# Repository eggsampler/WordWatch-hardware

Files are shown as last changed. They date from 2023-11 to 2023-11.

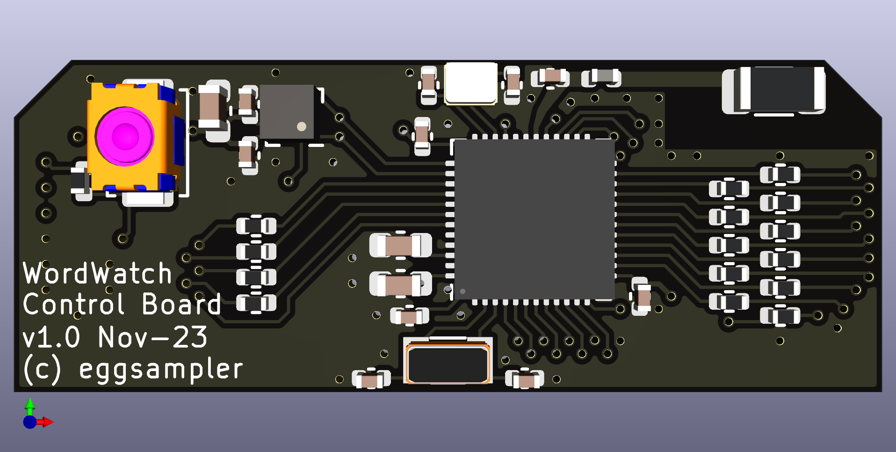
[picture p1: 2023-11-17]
ControllerBoard/plots/3d-front.png

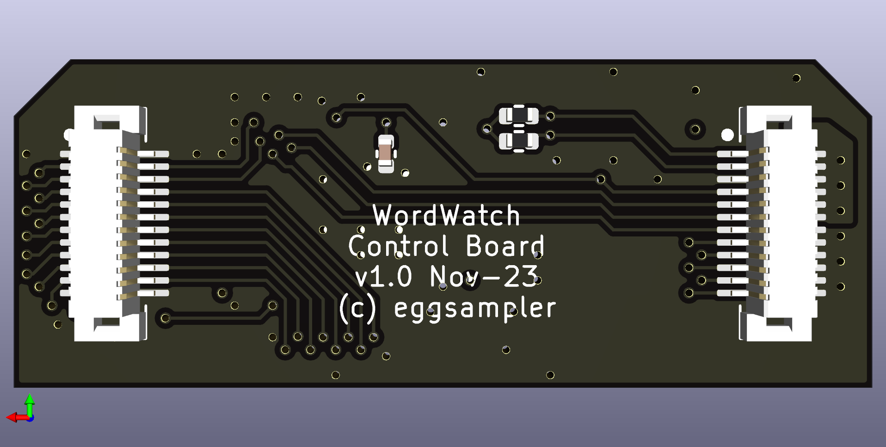
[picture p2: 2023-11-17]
ControllerBoard/plots/3d-back.png

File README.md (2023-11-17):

# WordWatch-hardware

|  | Schematic | 2D PCB | 3D |
| --- | --- | --- | --- |
| Controller Board | [ControllerBoard.pdf](ControllerBoard/plots/ControllerBoard.pdf) | [ControllerBoard__Assembly.pdf](ControllerBoard/plots/ControllerBoard__Assembly.pdf) | [ControllerBoard.wrl](ControllerBoard/plots/ControllerBoard.wrl) |
| LED Board | [LEDBoard.pdf](LEDBoard/plots/LEDBoard.pdf) | [LEDBoard__Assembly.pdf](LEDBoard/plots/LEDBoard__Assembly.pdf) | [LEDBoard.wrl](LEDBoard/plots/LEDBoard.wrl) |
| Programming Board | [ProgrammingBoard.pdf](ProgrammingBoard/plots/ProgrammingBoard.pdf) | [ProgrammingBoard__Assembly.pdf](ProgrammingBoard/plots/ProgrammingBoard__Assembly.pdf) | [ProgrammingBoard.wrl](ProgrammingBoard/plots/ProgrammingBoard.wrl) |

PNG outputs for 2D and 3D PCB views also in each plot folder.

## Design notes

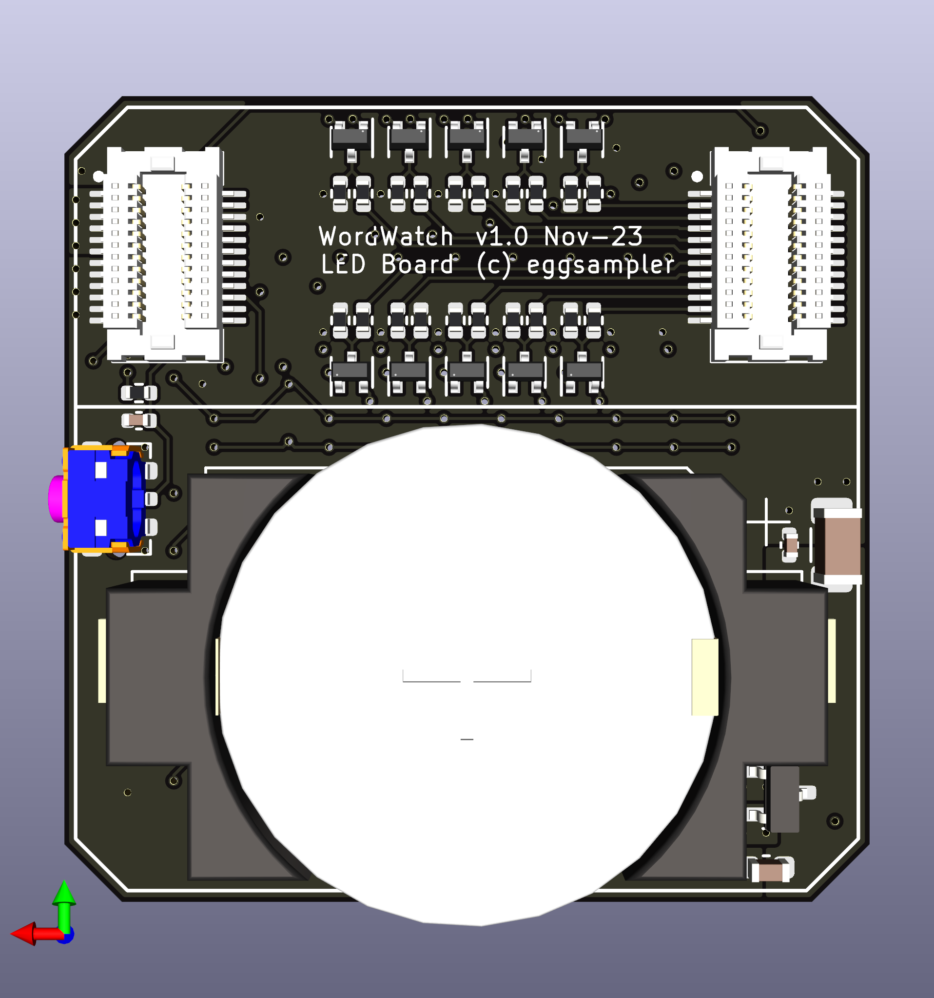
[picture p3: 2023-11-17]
LEDBoard/plots/3d-back.png

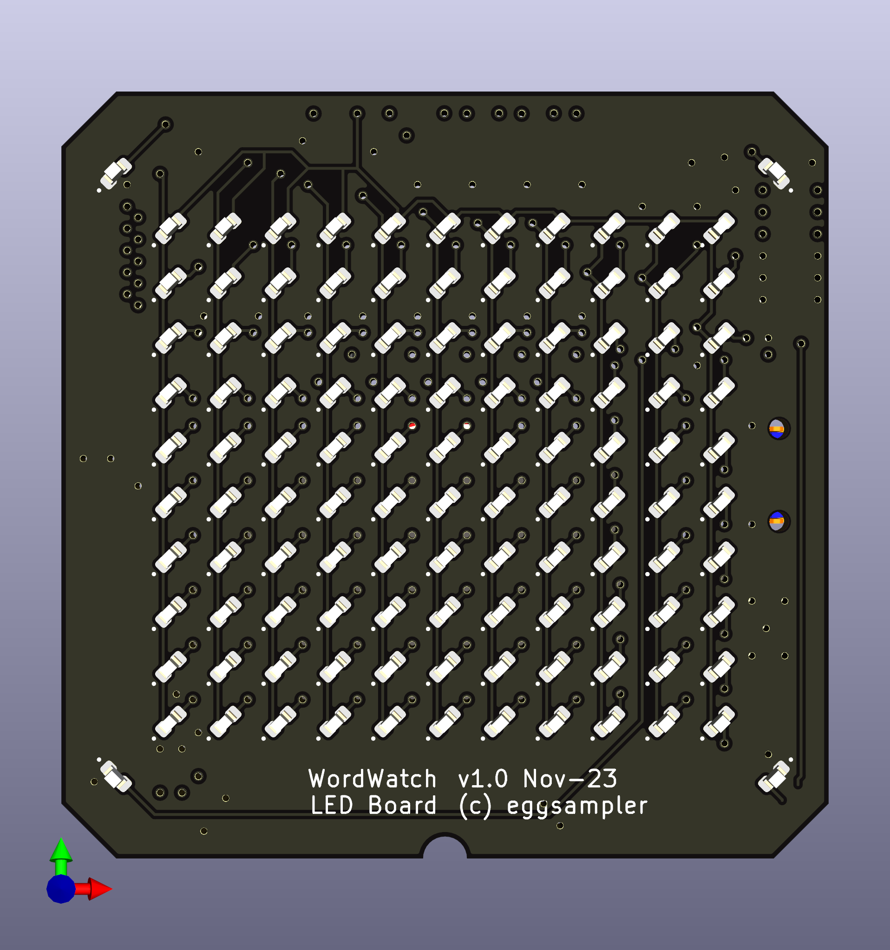
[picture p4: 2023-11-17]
LEDBoard/plots/3d-front.png

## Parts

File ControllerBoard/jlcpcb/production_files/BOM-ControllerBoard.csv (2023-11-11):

Comment | Designator | Footprint | LCSC
1k | R10,R11,R12,R13,R14,R15,R16,R17,R18,R4,R5,R6,R7,R8,R9 | R_0402_1005Metric | C11702
3.9nH | L1 | L_0402_1005Metric | C14033
nRF52810-QFxx | U3 | QFN-48-1EP_6x6mm_P0.4mm_EP4.6x4.6mm | C141828
100n | C1,C10,C13,C4,C9 | C_0402_1005Metric | C1525
100p | C11 | C_0402_1005Metric | C1546
12p | C12,C15,C16,C7 | C_0402_1005Metric | C1547
LIS2DE12 | U2 | LGA-12_2x2mm_P0.5mm | C155639
1u | C6 | C_0603_1608Metric | C15849
4.7u | C5,C8 | C_0603_1608Metric | C19666
4.7k | R1,R2,R3 | R_0402_1005Metric | C25900
RESET | SW1 | SW_Push_SPST_NO_Alps_SKRK | C262416
X0511WVS-24AS-LPV01 | J1,J2 | X0511WVS-24AS-LPV01 | C2925345
32MHz | Y2 | Oscillator_SMD_Abracon_ASCO-4Pin_1.6x1.2mm | C2965582
32.768kHz | Y1 | Crystal_SMD_3215-2Pin_3.2x1.5mm | C32346
0.8p | C14 | C_0402_1005Metric | C327032
KH3216-A55 | AE1 | R_1206_3216Metric | C484541

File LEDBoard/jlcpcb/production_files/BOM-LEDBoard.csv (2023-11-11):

Comment | Designator | Footprint | LCSC
SKRTLA | SW1 | SW_Push_1P1T-MP_NO_Horizontal_Alps_SKRTLAE010 | C110293
1k | R13,R14,R15,R16,R17,R18,R19,R20,R21,R22,R23,R24,R25,R26,R27,R28,R29,R30,R31,R32 | R_0402_1005Metric | C11702
100uF | C1 | C_1206_3216Metric | C15008
AO3401A | Q1 | SOT-23 | C15127
10uF | C3 | C_0603_1608Metric | C19702
DMG1012T | Q10,Q11,Q2,Q3,Q4,Q5,Q6,Q7,Q8,Q9 | SOT-523 | C20512
CR2032 | BT1 | BatteryHolder_Keystone_1060_1x2032 | C238069
10k | R7 | R_0402_1005Metric | C25744
X0511FVS-24AS-LPV01 | J1,J2 | X0511FVS-24AS-LPV01 | C2925346
LED_Small | D1,D10,D100,D101,D102,D103,D104,D105,D106,D107,D108,D109,D11,D110,D111,D112,D113,D114,D12,D13,D14,D15,D16,D17,D18,D19,D2,D20,D21,D22,D23,D24,D25,D26,D27,D28,D29,D3,D30,D31,D32,D33,D34,D35,D36,D37,D38,D39,D4,D40,D41,D42,D43,D44,D45,D46,D47,D48,D49,D5,D50,D51,D52,D53,D54,D55,D56,D57,D58,D59,D6,D60,D61,D62,D63,D64,D65,D66,D67,D68,D69,D7,D70,D71,D72,D73,D74,D75,D76,D77,D78,D79,D8,D80,D81,D82,D83,D84,D85,D86,D87,D88,D89,D9,D90,D91,D92,D93,D94,D95,D96,D97,D98,D99 | LED_0402_1005Metric | C434448
1uF | C2,C4 | C_0402_1005Metric | C52923

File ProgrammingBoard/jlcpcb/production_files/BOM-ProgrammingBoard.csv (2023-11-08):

Comment | Designator | Footprint | LCSC
X0511WVS-24AS-LPV01 | J1,J3 | X0511WVS-24AS-LPV01 | C2925345
X0511FVS-24AS-LPV01 | J2,J4 | X0511FVS-24AS-LPV01 | C2925346
Conn_01x09 | J6 | PinHeader_1x09_P2.54mm_Vertical
Conn_01x06 | J5 | PinHeader_1x06_P2.54mm_Vertical

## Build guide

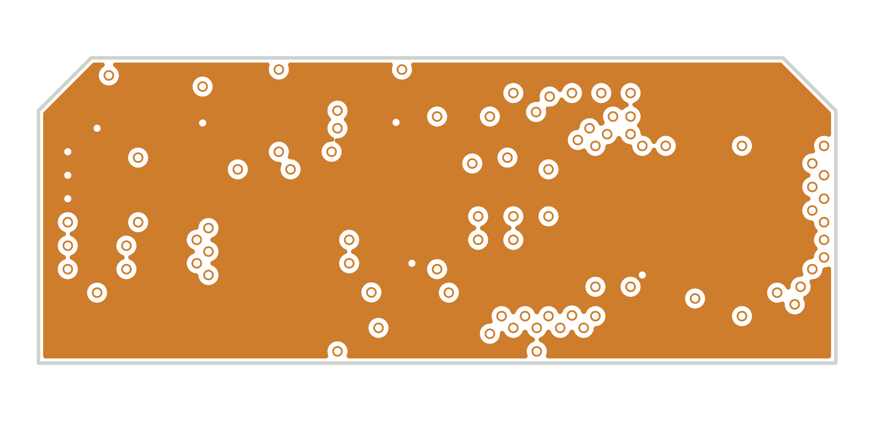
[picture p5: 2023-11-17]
ControllerBoard/plots/ControllerBoard__Assembly-3.png

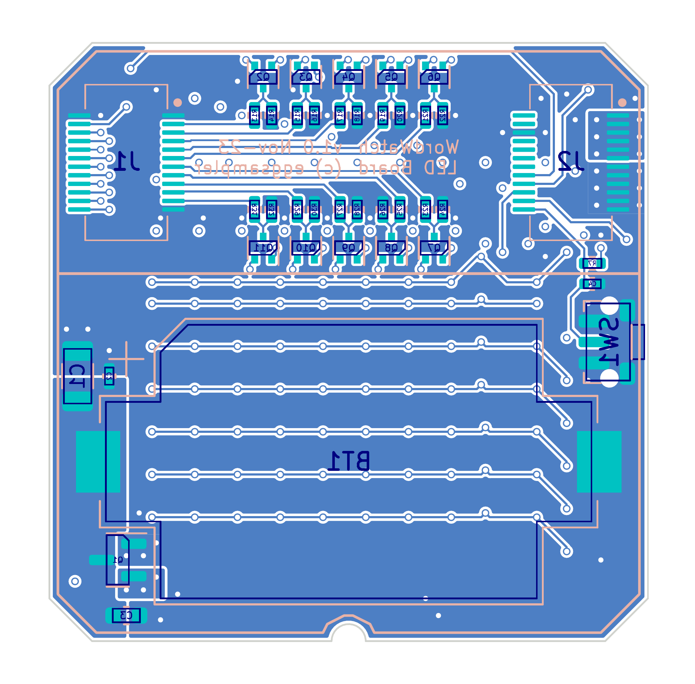
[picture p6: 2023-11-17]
LEDBoard/plots/LEDBoard__Assembly-4.png

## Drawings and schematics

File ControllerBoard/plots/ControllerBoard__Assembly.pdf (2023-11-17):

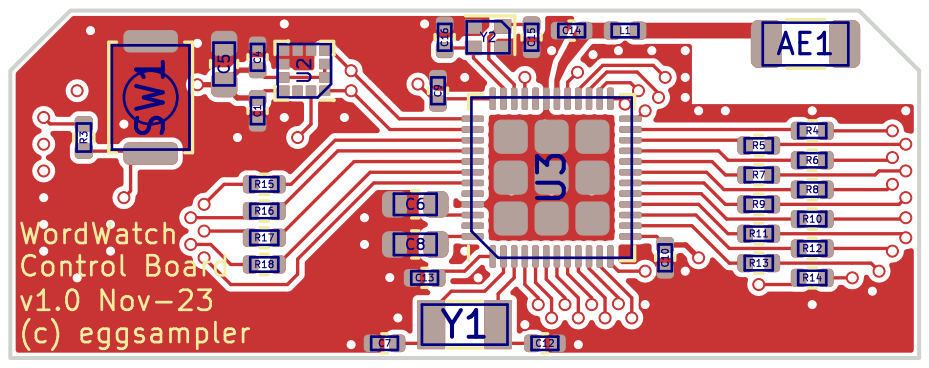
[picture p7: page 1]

Id: 1/1 Title: File: ControllerBoard.kicad_pcb Sheet:

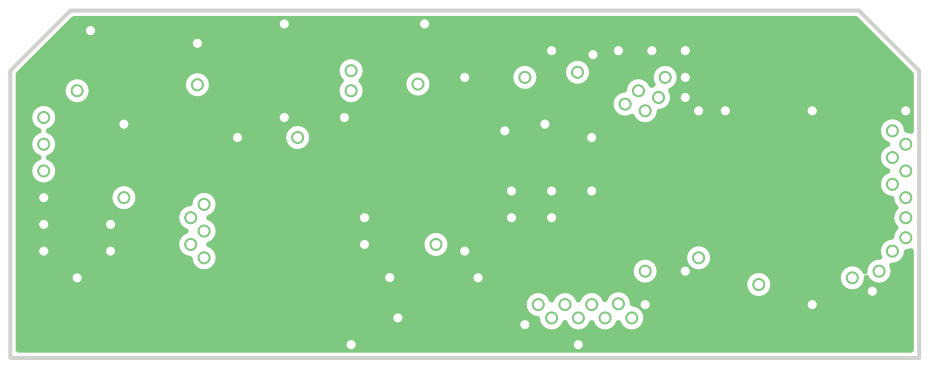
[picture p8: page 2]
D Date: KiCad; kicad; 7.0.8 Size: A4; Rev:

Id: 1/1 Title: File: ControllerBoard.kicad_pcb Sheet:

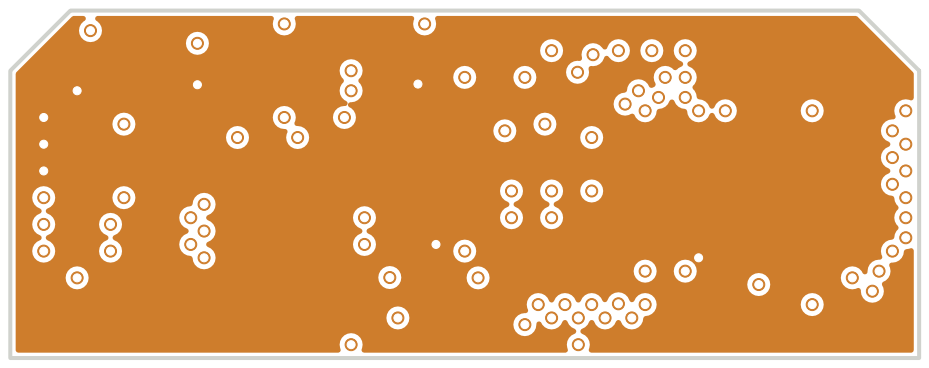
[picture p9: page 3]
D Date: KiCad; kicad; 7.0.8 Size: A4; Rev:

Id: 1/1 Title: File: ControllerBoard.kicad_pcb Sheet:

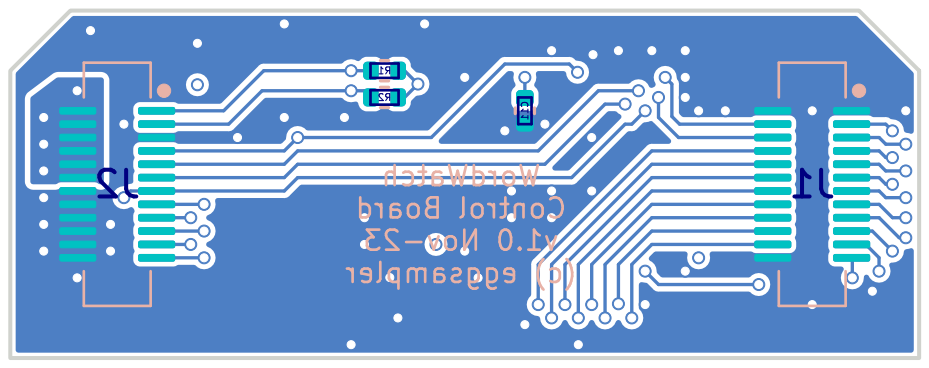
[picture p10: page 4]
C¹¹ R1; R2WordWatch Control Board; v1.0 Nov-23 (c) eggsampler; D Date: KiCad; kicad; 7.0.8 Size: A4; Rev:

Id: 1/1 Title: File: ControllerBoard.kicad_pcb Sheet:

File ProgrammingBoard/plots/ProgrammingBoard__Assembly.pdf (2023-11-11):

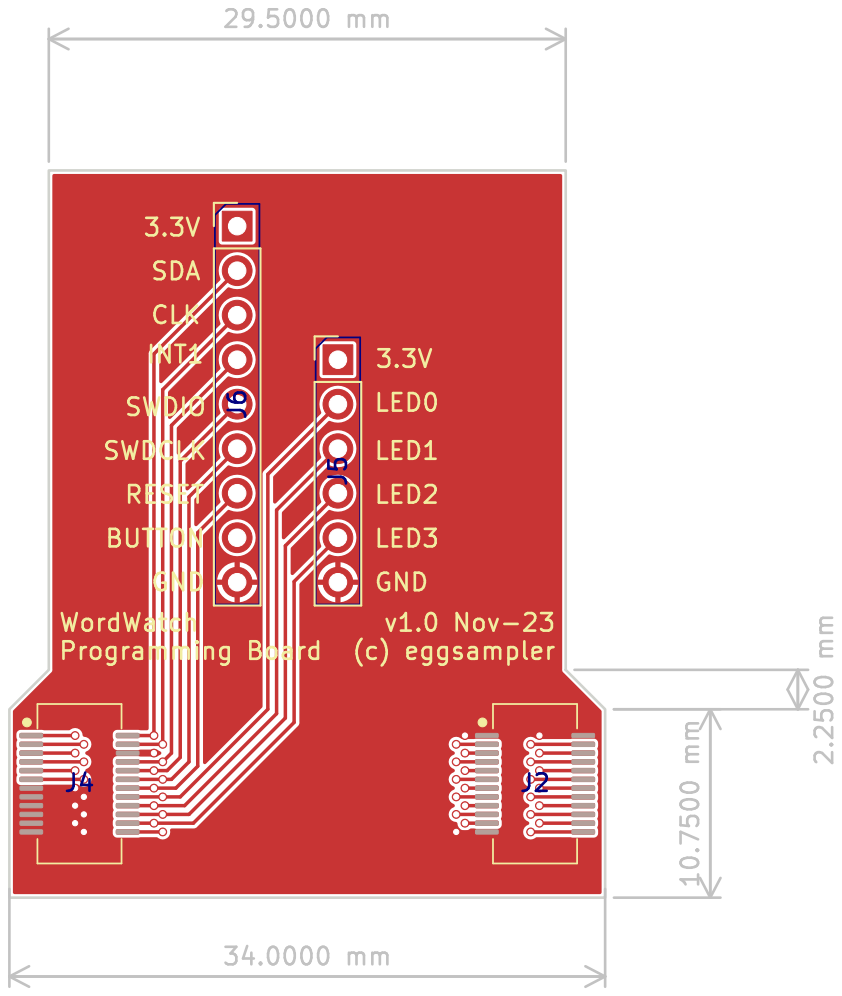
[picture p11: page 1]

Id: 1/1 Title: File: ProgrammingBoard.kicad_pcb Sheet:

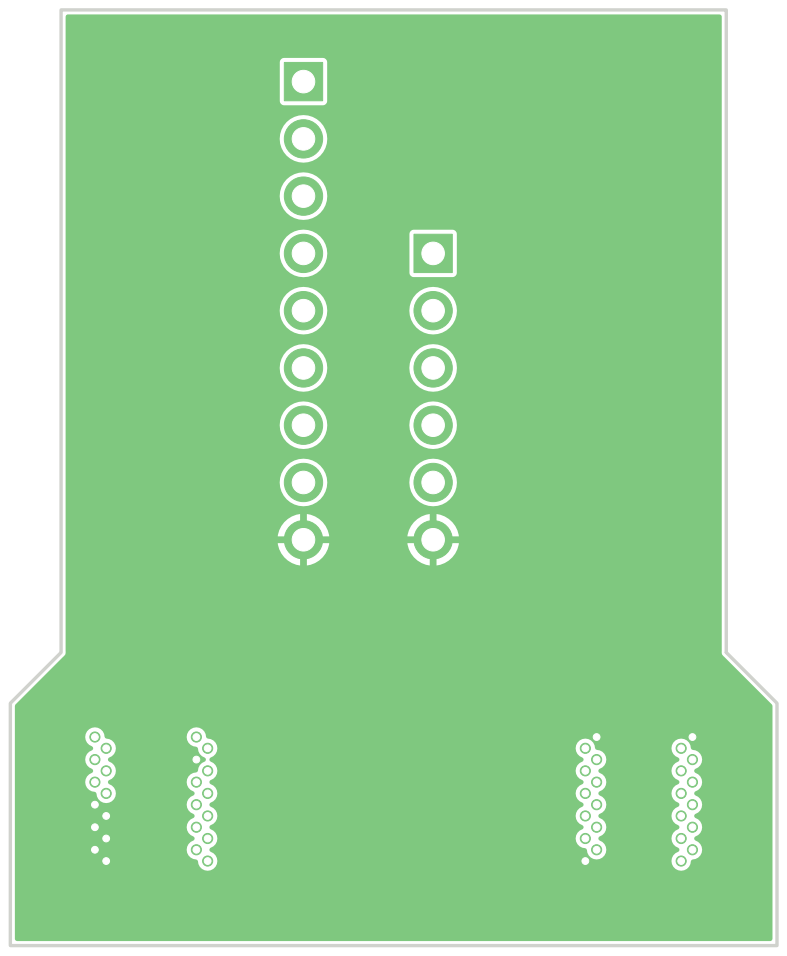
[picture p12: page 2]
D Date: KiCad; kicad; 7.0.8 Size: A4; Rev:

Id: 1/1 Title: File: ProgrammingBoard.kicad_pcb Sheet:

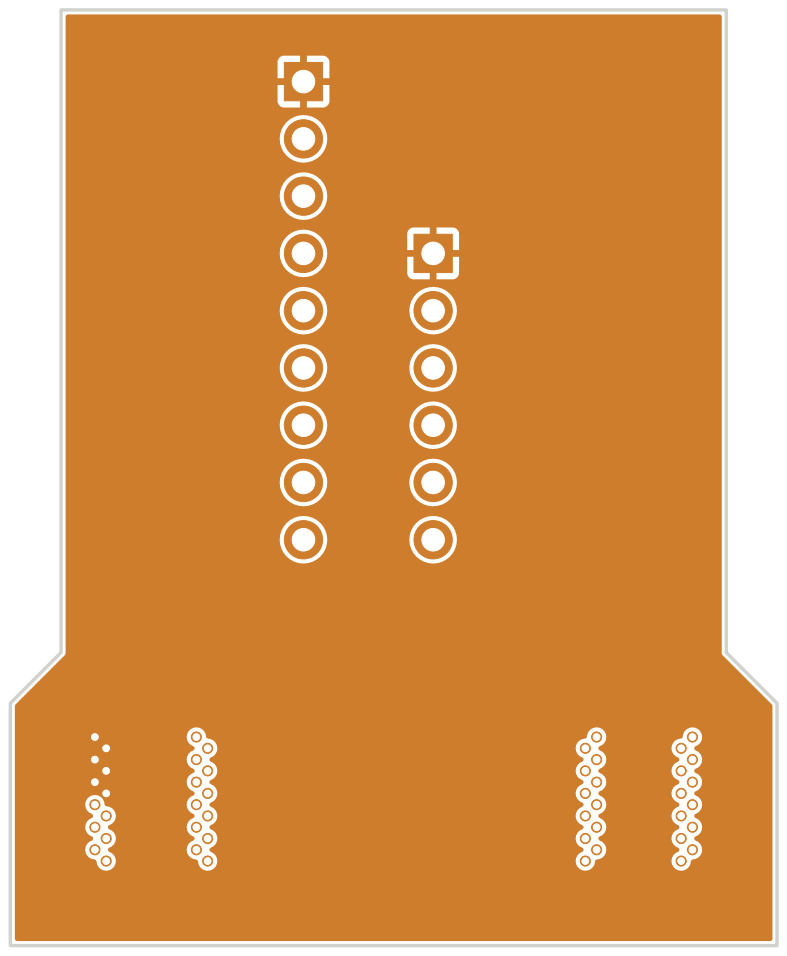
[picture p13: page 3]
D Date: KiCad; kicad; 7.0.8 Size: A4; Rev:

Id: 1/1 Title: File: ProgrammingBoard.kicad_pcb Sheet:

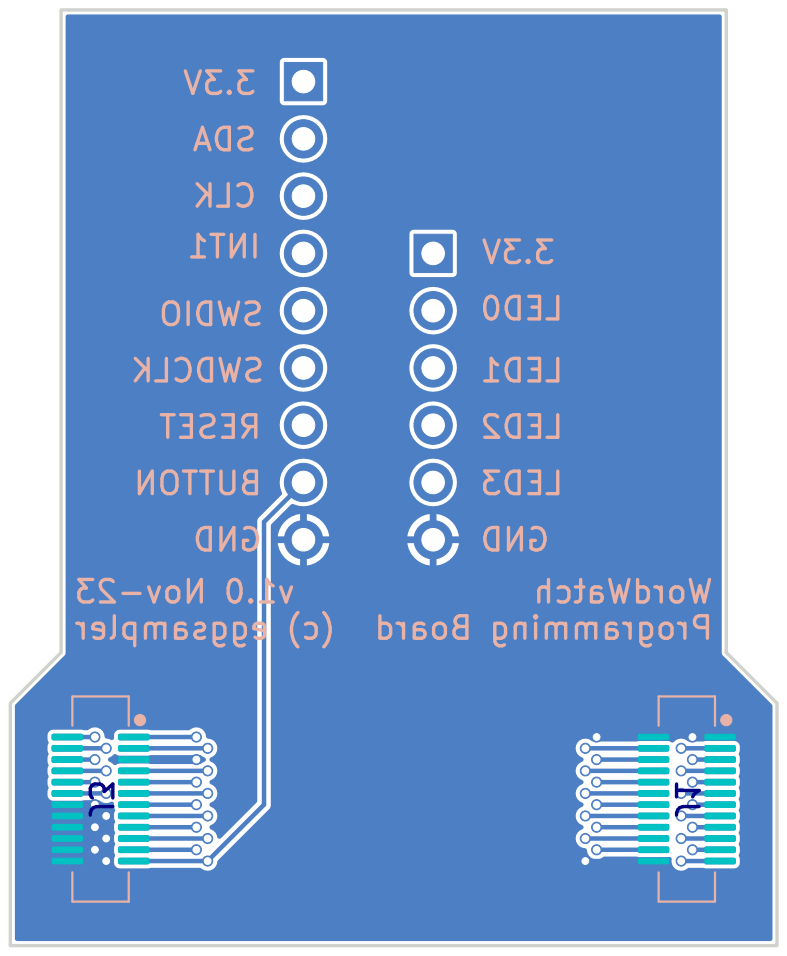
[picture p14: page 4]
J3J1 GND GND; SDA; LED2 SWDIO; LED1; v1.0 Nov-23 (c) eggsampler; INT1; LED3; 3.3V CLK; WordWatch Programming; Board SWDCLK; LED0; 3.3V RESET; BUTTON; D Date: KiCad; kicad; 7.0.8 Size: A4; Rev:

Id: 1/1 Title: File: ProgrammingBoard.kicad_pcb Sheet:

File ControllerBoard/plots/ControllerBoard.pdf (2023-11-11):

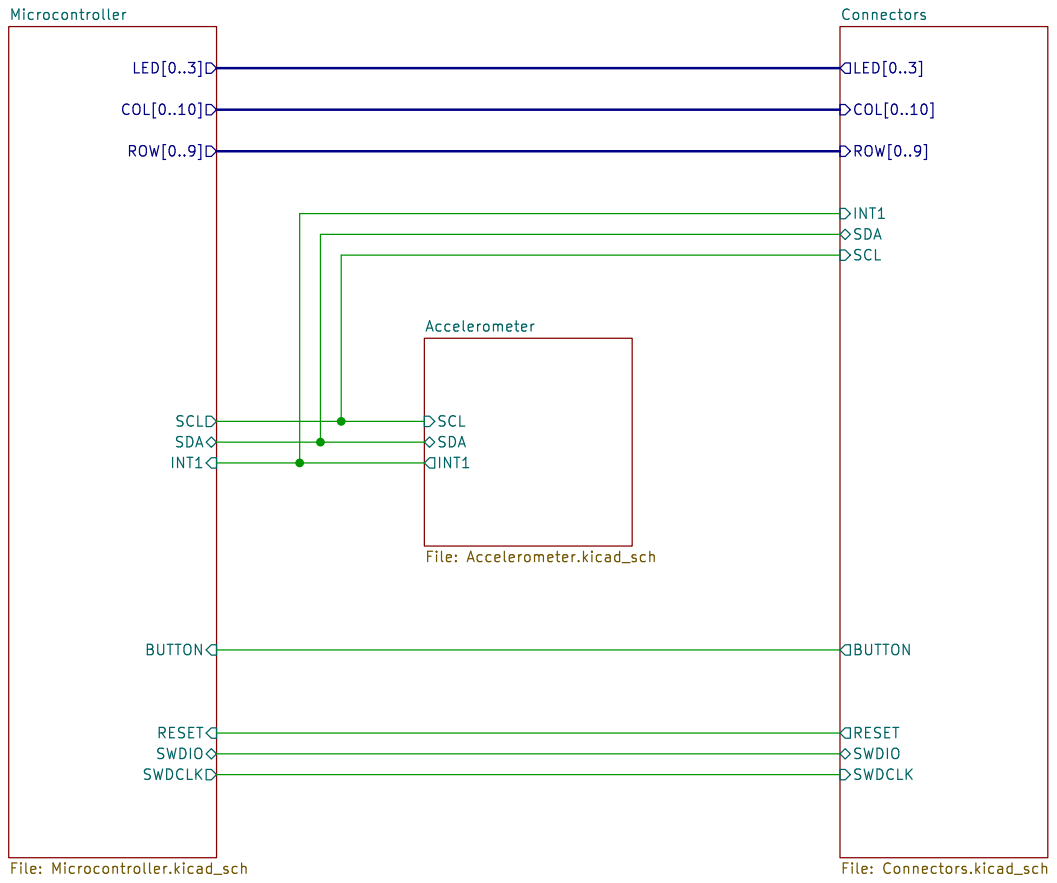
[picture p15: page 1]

SCL Accelerometer File: Accelerometer.kicad_sch

Date: 2023-11-11 File: ControllerBoard.kicad_sch

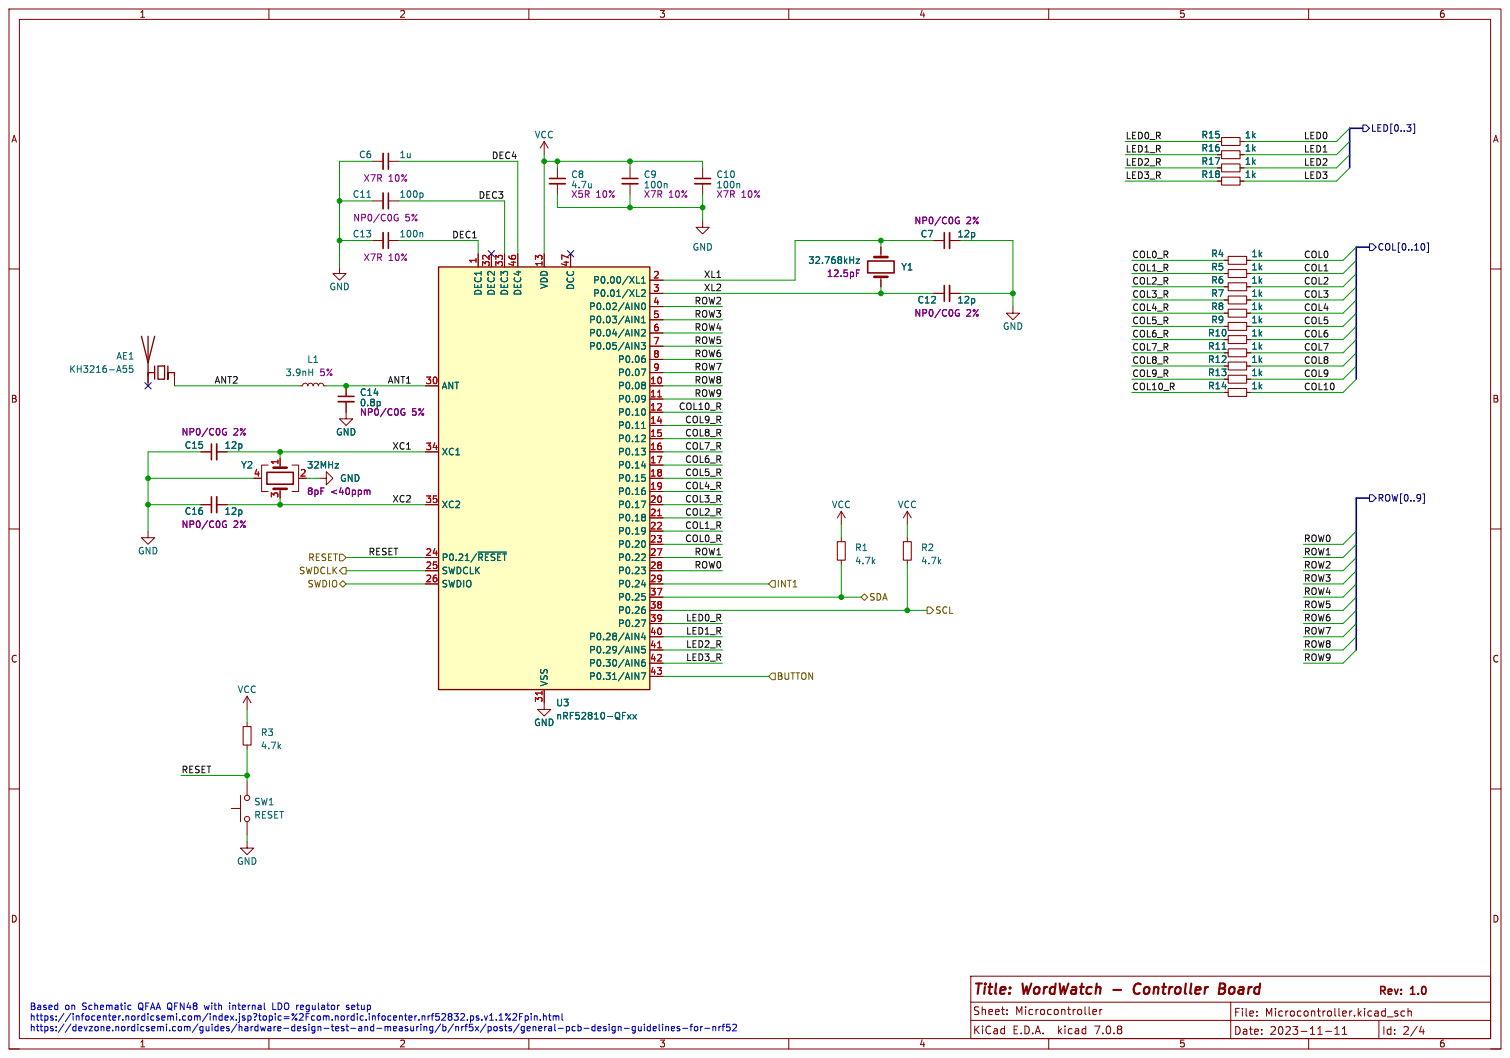
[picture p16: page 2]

1 P0.08 10 P0.09 11 P0.10 12 VDD 13 P0.11 14 P0.12 15 P0.13 16 P0.14 17 P0.15 18 P0.16 19 P0.00/XL1 2 P0.17 20 P0.18 21 P0.19 22 P0.20 23 P0.21/~{RESET} 24 SWDCLK 25 SWDIO 26 P0.22 27 P0.23 28 P0.24 29 P0.01/XL2 3 ANT 30 VSS 31 DEC2 32 DEC3 33 XC1 34 XC2 35 P0.25 37 P0.26 38 P0.27 39 P0.02/AIN0 4 P0.28/AIN4 40 P0.29/AIN5 41 P0.30/AIN6 42 P0.31/AIN7 43 DEC4 46 DCC 47 P0.03/AIN1 5 P0.04/AIN2 6 P0.05/AIN3 7 P0.06 8 P0.07 9 GND
GND

1 P0.08 10 P0.09 11 P0.10 12 VDD 13 P0.11 14 P0.12 15 P0.13 16 P0.14 17 P0.15 18 P0.16 19 P0.00/XL1 2 P0.17 20 P0.18 21 P0.19 22 P0.20 23 P0.21/~{RESET} 24 SWDCLK 25 SWDIO 26 P0.22 27 P0.23 28 P0.24 29 P0.01/XL2 3 ANT 30 VSS 31 DEC2 32 DEC3 33 XC1 34 XC2 35 P0.25 37 P0.26 38 P0.27 39 P0.02/AIN0 4 P0.28/AIN4 40 P0.29/AIN5 41 P0.30/AIN6 42 P0.31/AIN7 43 DEC4 46 DCC 47 P0.03/AIN1 5 P0.04/AIN2 6 P0.05/AIN3 7 P0.06 8 P0.07 9 U3

https://infocenter.nordicsemi.com/index.jsp?topic=%2Fcom.nordic.infocenter.nrf52832.ps.v1.1%2Fpin.html
https://devzone.nordicsemi.com/guides/hardware-design-test-and-measuring/b/nrf5x/posts/general-pcb-design-guidelines-for-nrf52

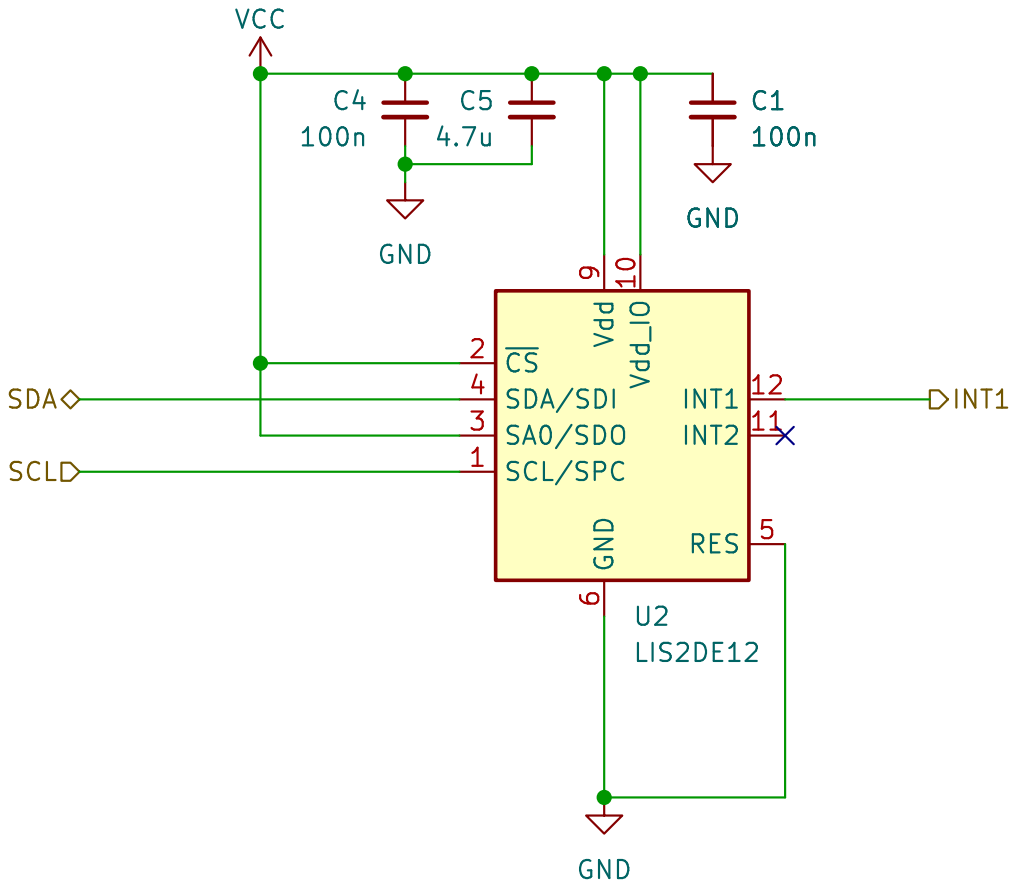
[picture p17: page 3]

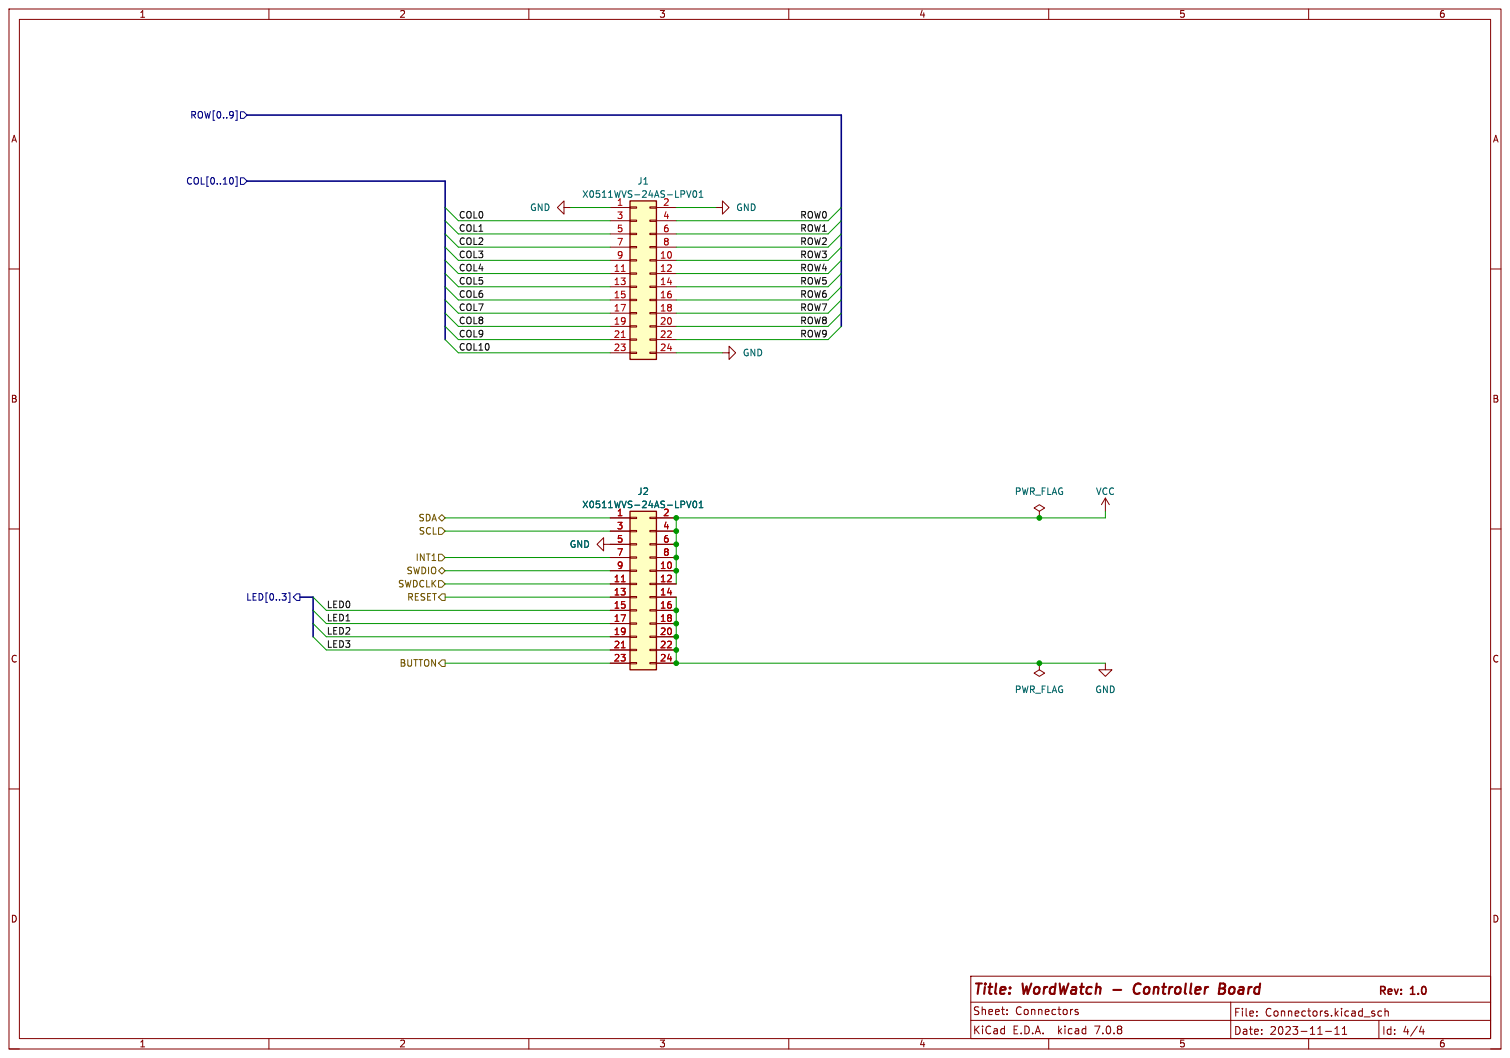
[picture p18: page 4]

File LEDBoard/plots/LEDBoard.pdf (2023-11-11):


17 17 | LED1 18 18
19 19 | 20 20
21 21 | 22 22 LED3
23 23 | 24 24

https://www.ti.com/lit/wp/swra349/swra349.pdf


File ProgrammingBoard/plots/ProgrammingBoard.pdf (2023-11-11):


SCL Connectors File: Connectors.kicad_sch

Programmer File: Programmer.kicad_sch SWDCLK



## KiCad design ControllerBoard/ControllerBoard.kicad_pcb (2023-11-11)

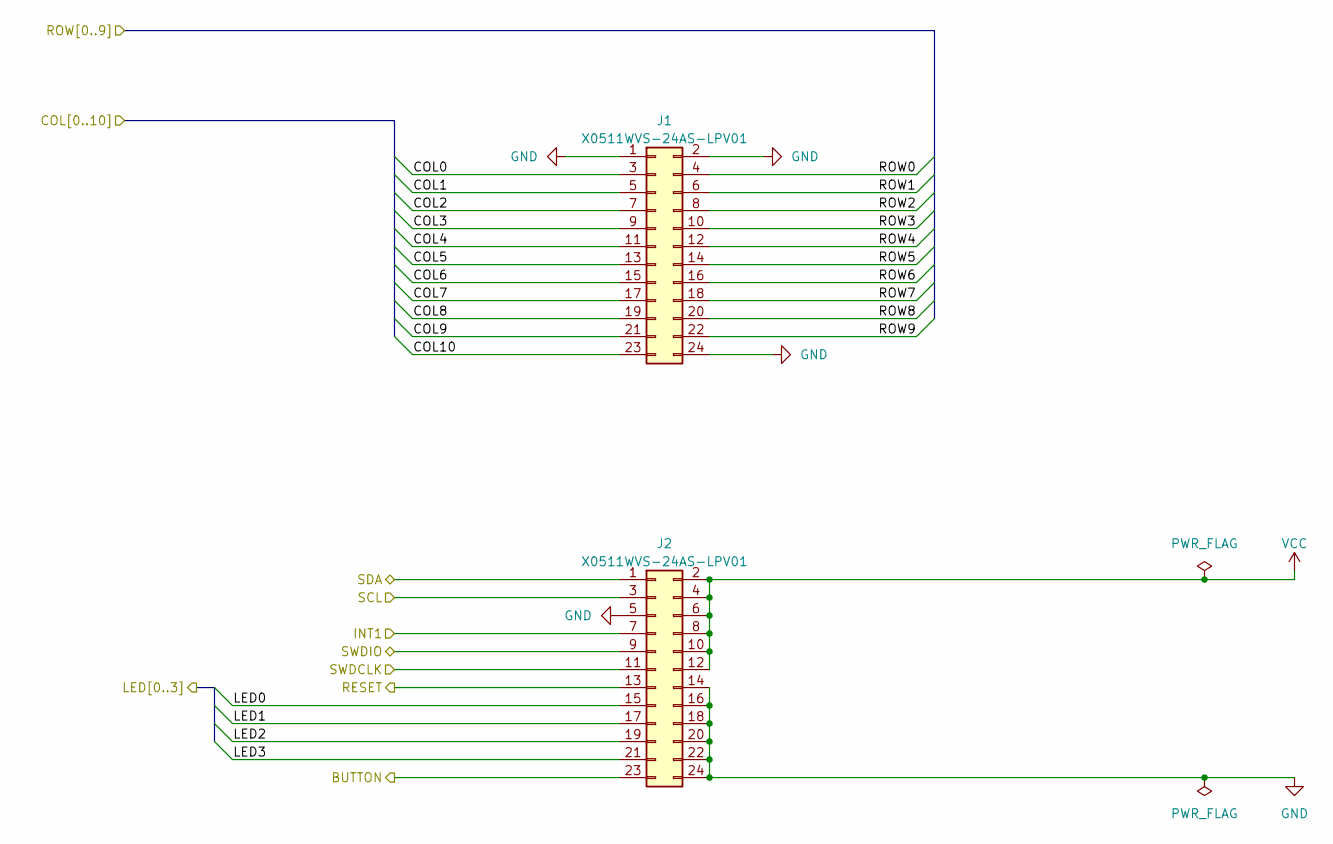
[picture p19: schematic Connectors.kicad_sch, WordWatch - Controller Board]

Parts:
J1, J2: X0511WVS-24AS-LPV01

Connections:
/Accelerometer/INT1: J2.7; also elsewhere on the board
/Accelerometer/SCL: J2.3; also elsewhere on the board
/Accelerometer/SDA: J2.1; also elsewhere on the board
/Connectors/BUTTON: J2.23; also elsewhere on the board
/Connectors/COL0: J1.3; also elsewhere on the board
/Connectors/COL1: J1.5; also elsewhere on the board
/Connectors/COL2: J1.7; also elsewhere on the board
/Connectors/COL3: J1.9; also elsewhere on the board
/Connectors/COL4: J1.11; also elsewhere on the board
/Connectors/COL5: J1.13; also elsewhere on the board
/Connectors/COL6: J1.15; also elsewhere on the board
/Connectors/COL7: J1.17; also elsewhere on the board
/Connectors/COL8: J1.19; also elsewhere on the board
/Connectors/COL9: J1.21; also elsewhere on the board
/Connectors/COL10: J1.23; also elsewhere on the board
/Connectors/LED0: J2.15; also elsewhere on the board
/Connectors/LED1: J2.17; also elsewhere on the board
/Connectors/LED2: J2.19; also elsewhere on the board
/Connectors/LED3: J2.21; also elsewhere on the board
/Connectors/ROW0: J1.4; also elsewhere on the board
/Connectors/ROW1: J1.6; also elsewhere on the board
/Connectors/ROW2: J1.8; also elsewhere on the board
/Connectors/ROW3: J1.10; also elsewhere on the board
/Connectors/ROW4: J1.12; also elsewhere on the board
/Connectors/ROW5: J1.14; also elsewhere on the board
/Connectors/ROW6: J1.16; also elsewhere on the board
/Connectors/ROW7: J1.18; also elsewhere on the board
/Connectors/ROW8: J1.20; also elsewhere on the board
/Connectors/ROW9: J1.22; also elsewhere on the board
/Connectors/SWDCLK: J2.11; also elsewhere on the board
/Connectors/SWDIO: J2.9; also elsewhere on the board
/Microcontroller/RESET: J2.13; also elsewhere on the board
GND: J1.1, J1.2, J1.24, J2.5, J2.14, J2.16, J2.18, J2.20, J2.22, J2.24; also elsewhere on the board
VCC: J2.2, J2.4, J2.6, J2.8, J2.10, J2.12; also elsewhere on the board

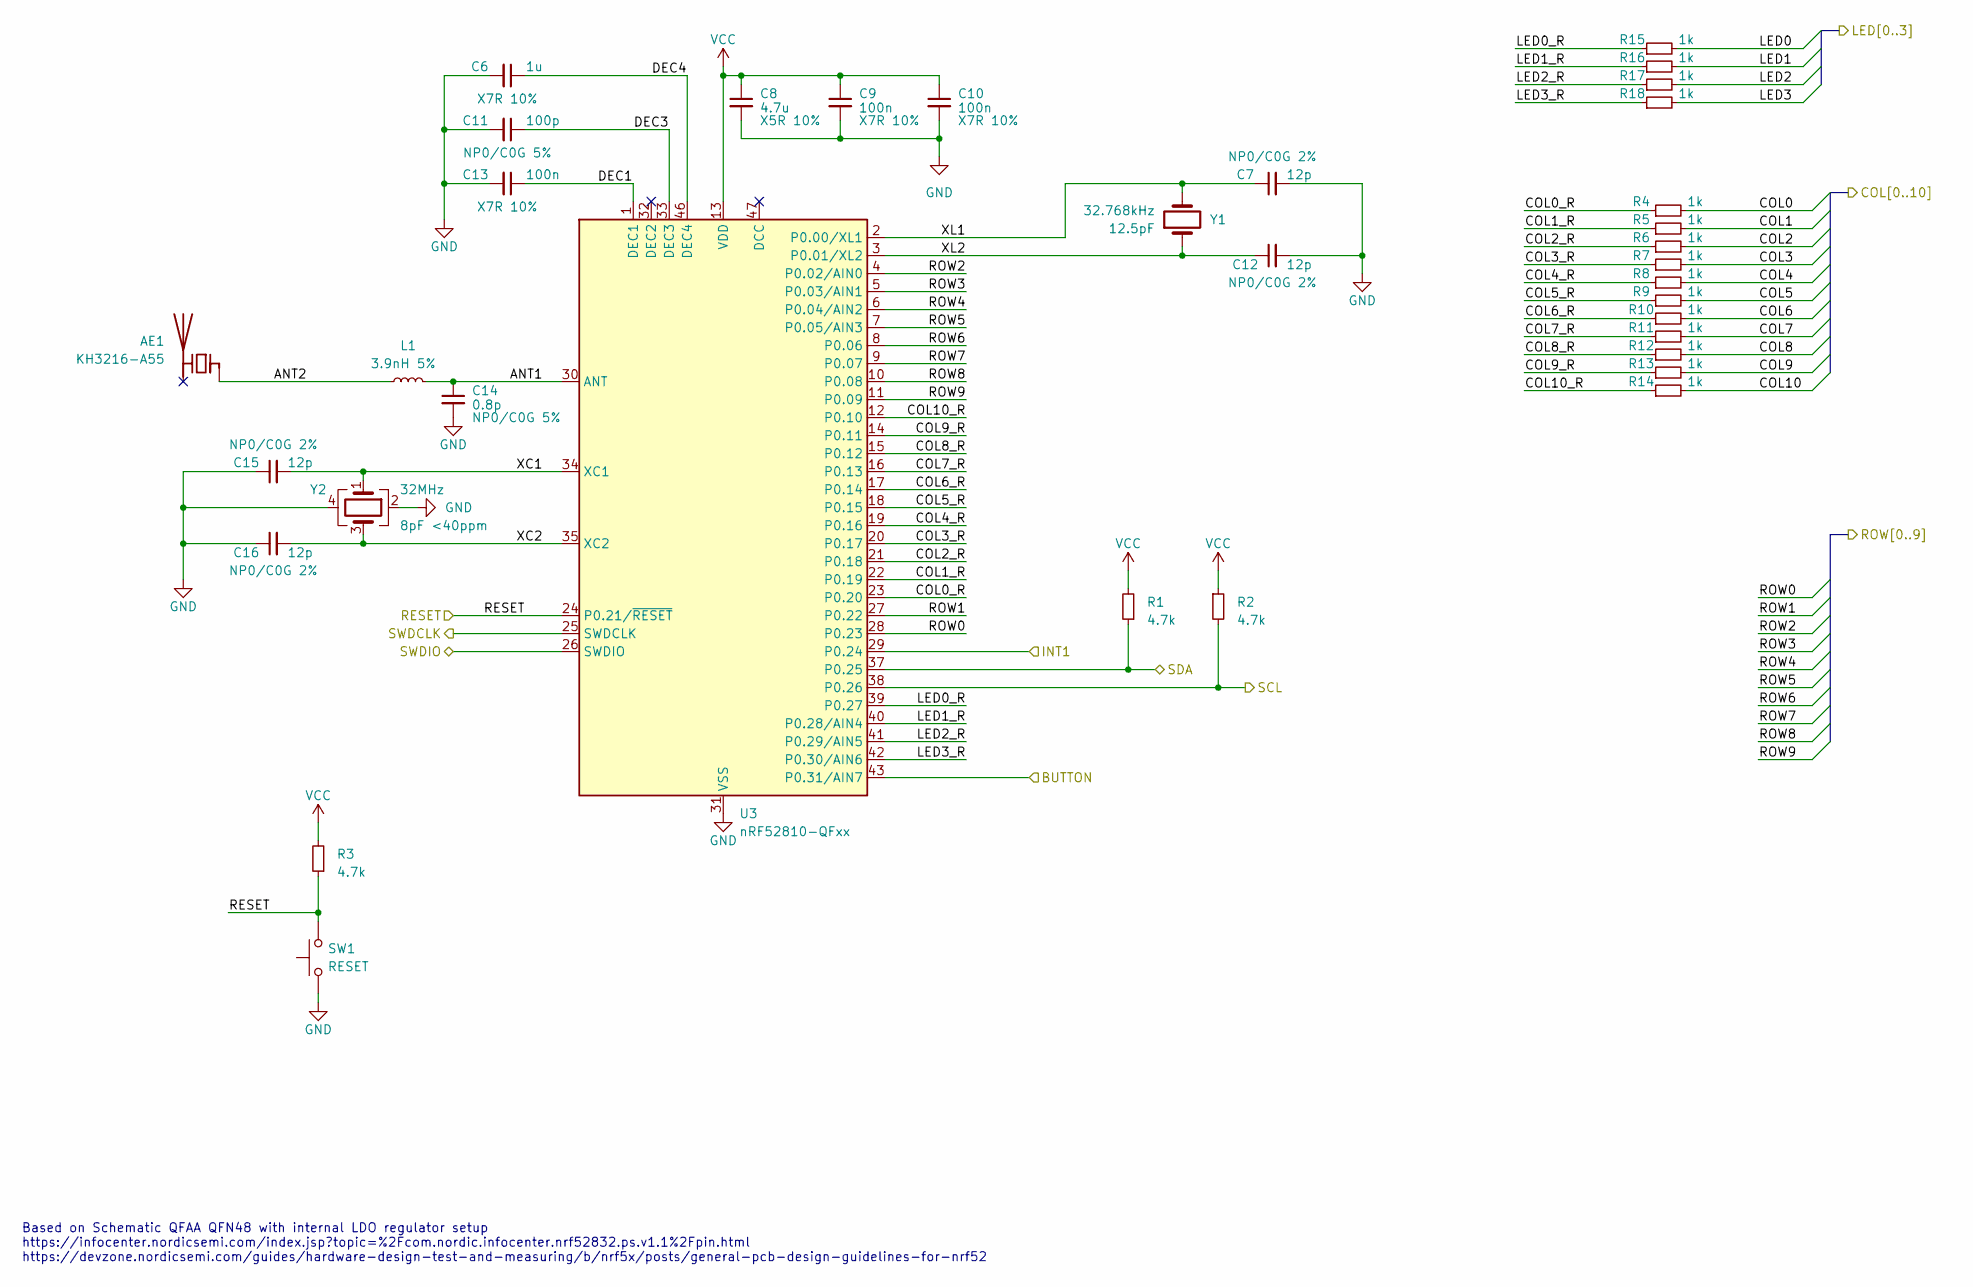
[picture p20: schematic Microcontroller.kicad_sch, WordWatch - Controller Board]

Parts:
AE1: KH3216-A55; R_1206_3216Metric
C6: 1u; C_0603_1608Metric
C7, C12, C15, C16: 12p; C_0402_1005Metric
C8: 4.7u; C_0603_1608Metric
C9, C10, C13: 100n; C_0402_1005Metric
C11: 100p; C_0402_1005Metric
C14: 0.8p; C_0402_1005Metric
L1: 3.9nH; L_0402_1005Metric
R1, R2, R3: 4.7k; R_0402_1005Metric
R4, R5, R6, R7, R8, R9, R10, R11, R12, R13, R14, R15, R16, R17, R18: 1k; R_0402_1005Metric
SW1: RESET; SW_Push_SPST_NO_Alps_SKRK
U3: nRF52810-QFxx; QFN-48-1EP_6x6mm_P0.4mm_EP4.6x4.6mm
Y1: 32.768kHz; Crystal_SMD_3215-2Pin_3.2x1.5mm
Y2: 32MHz; Oscillator_SMD_Abracon_ASCO-4Pin_1.6x1.2mm

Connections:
/Accelerometer/INT1: U3.29 (P0.24); also elsewhere on the board
/Accelerometer/SCL: R2.2, U3.38 (P0.26); also elsewhere on the board
/Accelerometer/SDA: R1.1, U3.37 (P0.25); also elsewhere on the board
/Connectors/BUTTON: U3.43 (P0.31/AIN7); also elsewhere on the board
/Connectors/COL0: R4.2; also elsewhere on the board
/Connectors/COL1: R5.2; also elsewhere on the board
/Connectors/COL2: R6.2; also elsewhere on the board
/Connectors/COL3: R7.2; also elsewhere on the board
/Connectors/COL4: R8.2; also elsewhere on the board
/Connectors/COL5: R9.2; also elsewhere on the board
/Connectors/COL6: R10.2; also elsewhere on the board
/Connectors/COL7: R11.2; also elsewhere on the board
/Connectors/COL8: R12.2; also elsewhere on the board
/Connectors/COL9: R13.2; also elsewhere on the board
/Connectors/COL10: R14.2; also elsewhere on the board
/Connectors/LED0: R15.2; also elsewhere on the board
/Connectors/LED1: R16.2; also elsewhere on the board
/Connectors/LED2: R17.2; also elsewhere on the board
/Connectors/LED3: R18.2; also elsewhere on the board
/Connectors/ROW0: U3.28 (P0.23); also elsewhere on the board
/Connectors/ROW1: U3.27 (P0.22); also elsewhere on the board
/Connectors/ROW2: U3.4 (P0.02/AIN0); also elsewhere on the board
/Connectors/ROW3: U3.5 (P0.03/AIN1); also elsewhere on the board
/Connectors/ROW4: U3.6 (P0.04/AIN2); also elsewhere on the board
/Connectors/ROW5: U3.7 (P0.05/AIN3); also elsewhere on the board
/Connectors/ROW6: U3.8 (P0.06); also elsewhere on the board
/Connectors/ROW7: U3.9 (P0.07); also elsewhere on the board
/Connectors/ROW8: U3.10 (P0.08); also elsewhere on the board
/Connectors/ROW9: U3.11 (P0.09); also elsewhere on the board
/Connectors/SWDCLK: U3.25 (SWDCLK); also elsewhere on the board
/Connectors/SWDIO: U3.26 (SWDIO); also elsewhere on the board
/Microcontroller/ANT1: C14.1, L1.2, U3.30 (ANT)
/Microcontroller/ANT2: AE1.1 (FEED), L1.1
/Microcontroller/COL0_R: R4.1, U3.23 (P0.20)
/Microcontroller/COL1_R: R5.1, U3.22 (P0.19)
/Microcontroller/COL2_R: R6.1, U3.21 (P0.18)
/Microcontroller/COL3_R: R7.1, U3.20 (P0.17)
/Microcontroller/COL4_R: R8.1, U3.19 (P0.16)
/Microcontroller/COL5_R: R9.1, U3.18 (P0.15)
/Microcontroller/COL6_R: R10.1, U3.17 (P0.14)
/Microcontroller/COL7_R: R11.1, U3.16 (P0.13)
/Microcontroller/COL8_R: R12.1, U3.15 (P0.12)
/Microcontroller/COL9_R: R13.1, U3.14 (P0.11)
/Microcontroller/COL10_R: R14.1, U3.12 (P0.10)
/Microcontroller/DEC1: C13.1, U3.1 (DEC1)
/Microcontroller/DEC3: C11.1, U3.33 (DEC3)
/Microcontroller/DEC4: C6.1, U3.46 (DEC4)
/Microcontroller/LED0_R: R15.1, U3.39 (P0.27)
/Microcontroller/LED1_R: R16.1, U3.40 (P0.28/AIN4)
/Microcontroller/LED2_R: R17.1, U3.41 (P0.29/AIN5)
/Microcontroller/LED3_R: R18.1, U3.42 (P0.30/AIN6)
/Microcontroller/RESET: R3.1, SW1.2, U3.24 (P0.21/~RESET); also elsewhere on the board
/Microcontroller/XC1: C15.2, U3.34 (XC1), Y2.1
/Microcontroller/XC2: C16.2, U3.35 (XC2), Y2.3
/Microcontroller/XL1: C7.1, U3.2 (P0.00/XL1), Y1.2
/Microcontroller/XL2: C12.1, U3.3 (P0.01/XL2), Y1.1
GND: C6.2, C7.2, C8.2, C9.2, C10.2, C11.2, C12.2, C13.2, C14.2, C15.1, C16.1, SW1.1, U3.31 (VSS), U3.45 (VSS), U3.49 (VSS), Y2.2, Y2.4; also elsewhere on the board
VCC: C8.1, C9.1, C10.1, R1.2, R2.1, R3.2, U3.13 (VDD), U3.36 (VDD), U3.48 (VDD); also elsewhere on the board

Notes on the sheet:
Based on Schematic QFAA QFN48 with internal LDO regulator setup https://infocenter.nordicsemi.com/index.jsp?topic=%2Fcom.nordic.infocenter.nrf52832.ps.v1.1%2Fpin.html https://devzone.nordicsemi.com/guides/hardware-design-test-and-measuring/b/nrf5x/posts/general-pcb-design-guidelines-for-nrf52

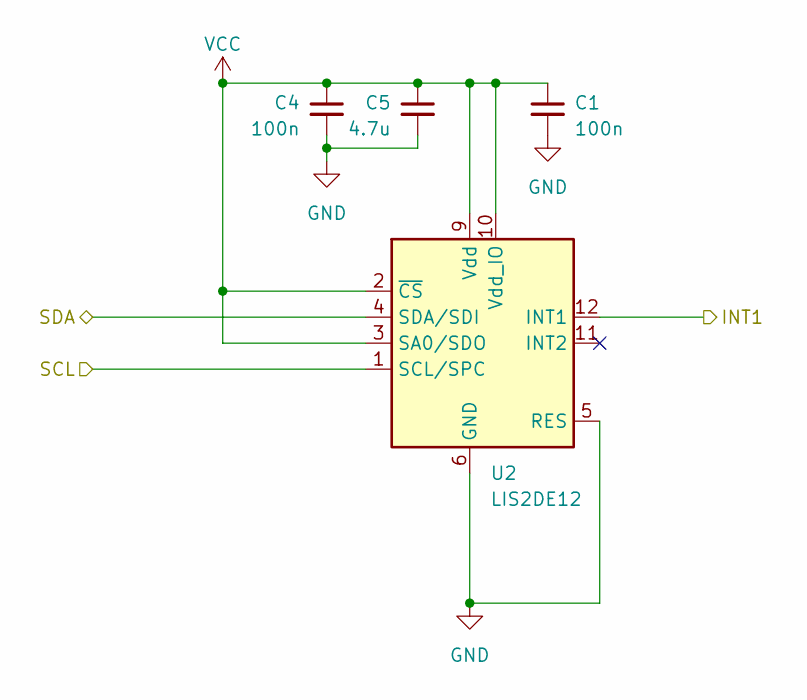
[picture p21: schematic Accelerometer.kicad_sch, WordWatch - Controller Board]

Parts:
C1, C4: 100n; C_0402_1005Metric
C5: 4.7u; C_0603_1608Metric
U2: LIS2DE12; LGA-12_2x2mm_P0.5mm

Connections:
/Accelerometer/INT1: U2.12 (INT1); also elsewhere on the board
/Accelerometer/SCL: U2.1 (SCL/SPC); also elsewhere on the board
/Accelerometer/SDA: U2.4 (SDA/SDI); also elsewhere on the board
GND: C1.2, C4.2, C5.2, U2.5 (RES), U2.6 (GND), U2.7 (GND), U2.8 (GND); also elsewhere on the board
VCC: C1.1, C4.1, C5.1, U2.2 (~CS), U2.3 (SA0/SDO), U2.9 (Vdd), U2.10 (Vdd_IO); also elsewhere on the board

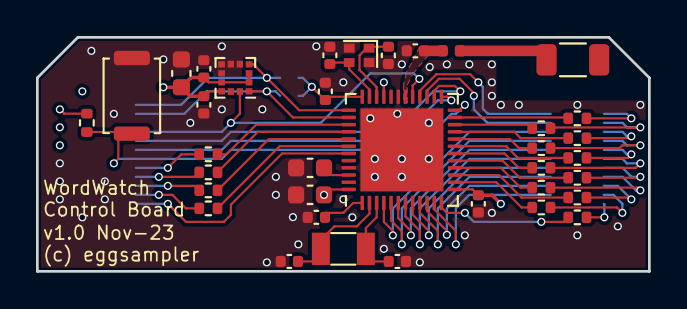
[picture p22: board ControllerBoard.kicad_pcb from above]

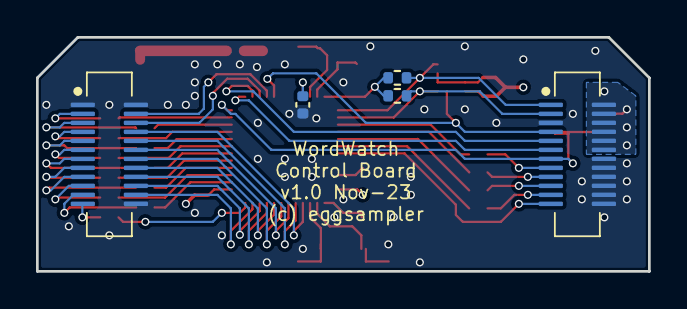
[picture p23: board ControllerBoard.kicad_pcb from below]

Board: 4 copper layers, 34.0 x 13.0 mm, 41 parts (5 on the bottom side), 58 nets.

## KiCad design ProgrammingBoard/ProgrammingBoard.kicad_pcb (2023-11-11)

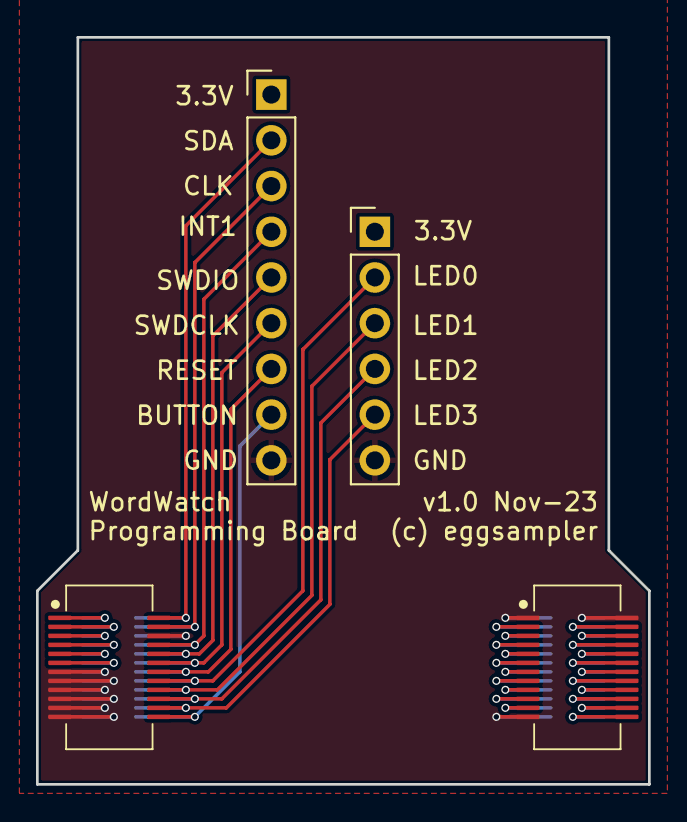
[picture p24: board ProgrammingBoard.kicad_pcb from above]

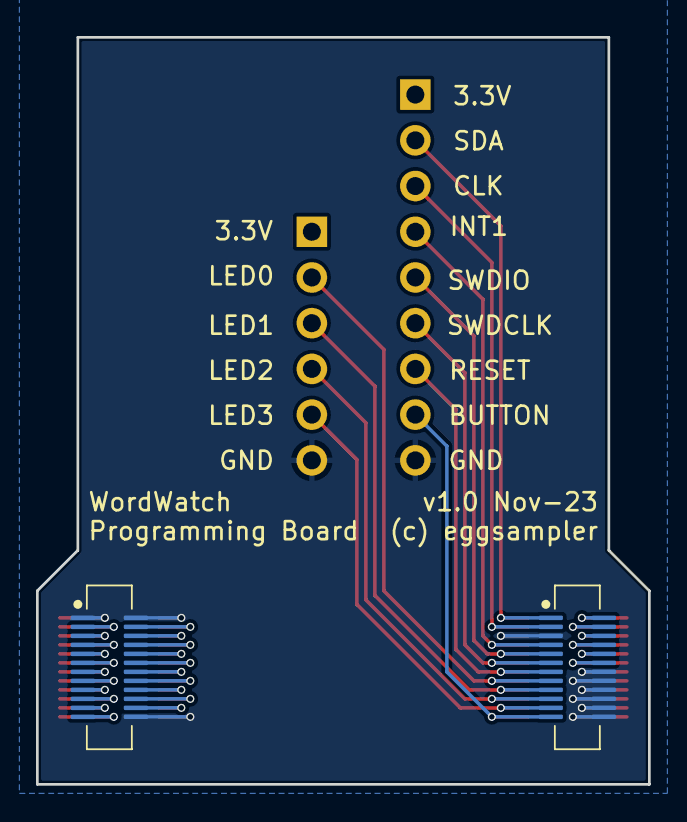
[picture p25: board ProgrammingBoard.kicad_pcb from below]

Board: 4 copper layers, 34.0 x 41.5 mm, 6 parts (2 on the bottom side), 34 nets.

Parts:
J1, J3: X0511WVS-24AS-LPV01
J2, J4: X0511FVS-24AS-LPV01
J5: Conn_01x06; PinHeader_1x06_P2.54mm_Vertical
J6: Conn_01x09; PinHeader_1x09_P2.54mm_Vertical

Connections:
/Connectors/BUTTON: J3.23, J4.24, J6.8
/Connectors/COL0: J1.3, J2.4
/Connectors/COL1: J1.5, J2.6
/Connectors/COL2: J1.7, J2.8
/Connectors/COL3: J1.9, J2.10
/Connectors/COL4: J1.11, J2.12
/Connectors/COL5: J1.13, J2.14
/Connectors/COL6: J1.15, J2.16
/Connectors/COL7: J1.17, J2.18
/Connectors/COL8: J1.19, J2.20
/Connectors/COL9: J1.21, J2.22
/Connectors/COL10: J1.23, J2.24
/Connectors/INT1: J3.7, J4.8, J6.4
/Connectors/LED0: J3.15, J4.16, J5.2
/Connectors/LED1: J3.17, J4.18, J5.3
/Connectors/LED2: J3.19, J4.20, J5.4
/Connectors/LED3: J3.21, J4.22, J5.5
/Connectors/RESET: J3.13, J4.14, J6.7
/Connectors/ROW0: J1.4, J2.3
/Connectors/ROW1: J1.6, J2.5
/Connectors/ROW2: J1.8, J2.7
/Connectors/ROW3: J1.10, J2.9
/Connectors/ROW4: J1.12, J2.11
/Connectors/ROW5: J1.14, J2.13
/Connectors/ROW6: J1.16, J2.15
/Connectors/ROW7: J1.18, J2.17
/Connectors/ROW8: J1.20, J2.19
/Connectors/ROW9: J1.22, J2.21
/Connectors/SCL: J3.3, J4.4, J6.3
/Connectors/SDA: J3.1, J4.2, J6.2
/Connectors/SWDCLK: J3.11, J4.12, J6.6
/Connectors/SWDIO: J3.9, J4.10, J6.5
GND: J1.1, J1.2, J1.24, J2.1, J2.2, J2.23, J3.5, J3.14, J3.16, J3.18, J3.20, J3.22, J3.24, J4.6, J4.13, J4.15, J4.17, J4.19, J4.21, J4.23, J5.6, J6.9
VCC: J3.2, J3.4, J3.6, J3.8, J3.10, J3.12, J4.1, J4.3, J4.5, J4.7, J4.9, J4.11, J5.1, J6.1

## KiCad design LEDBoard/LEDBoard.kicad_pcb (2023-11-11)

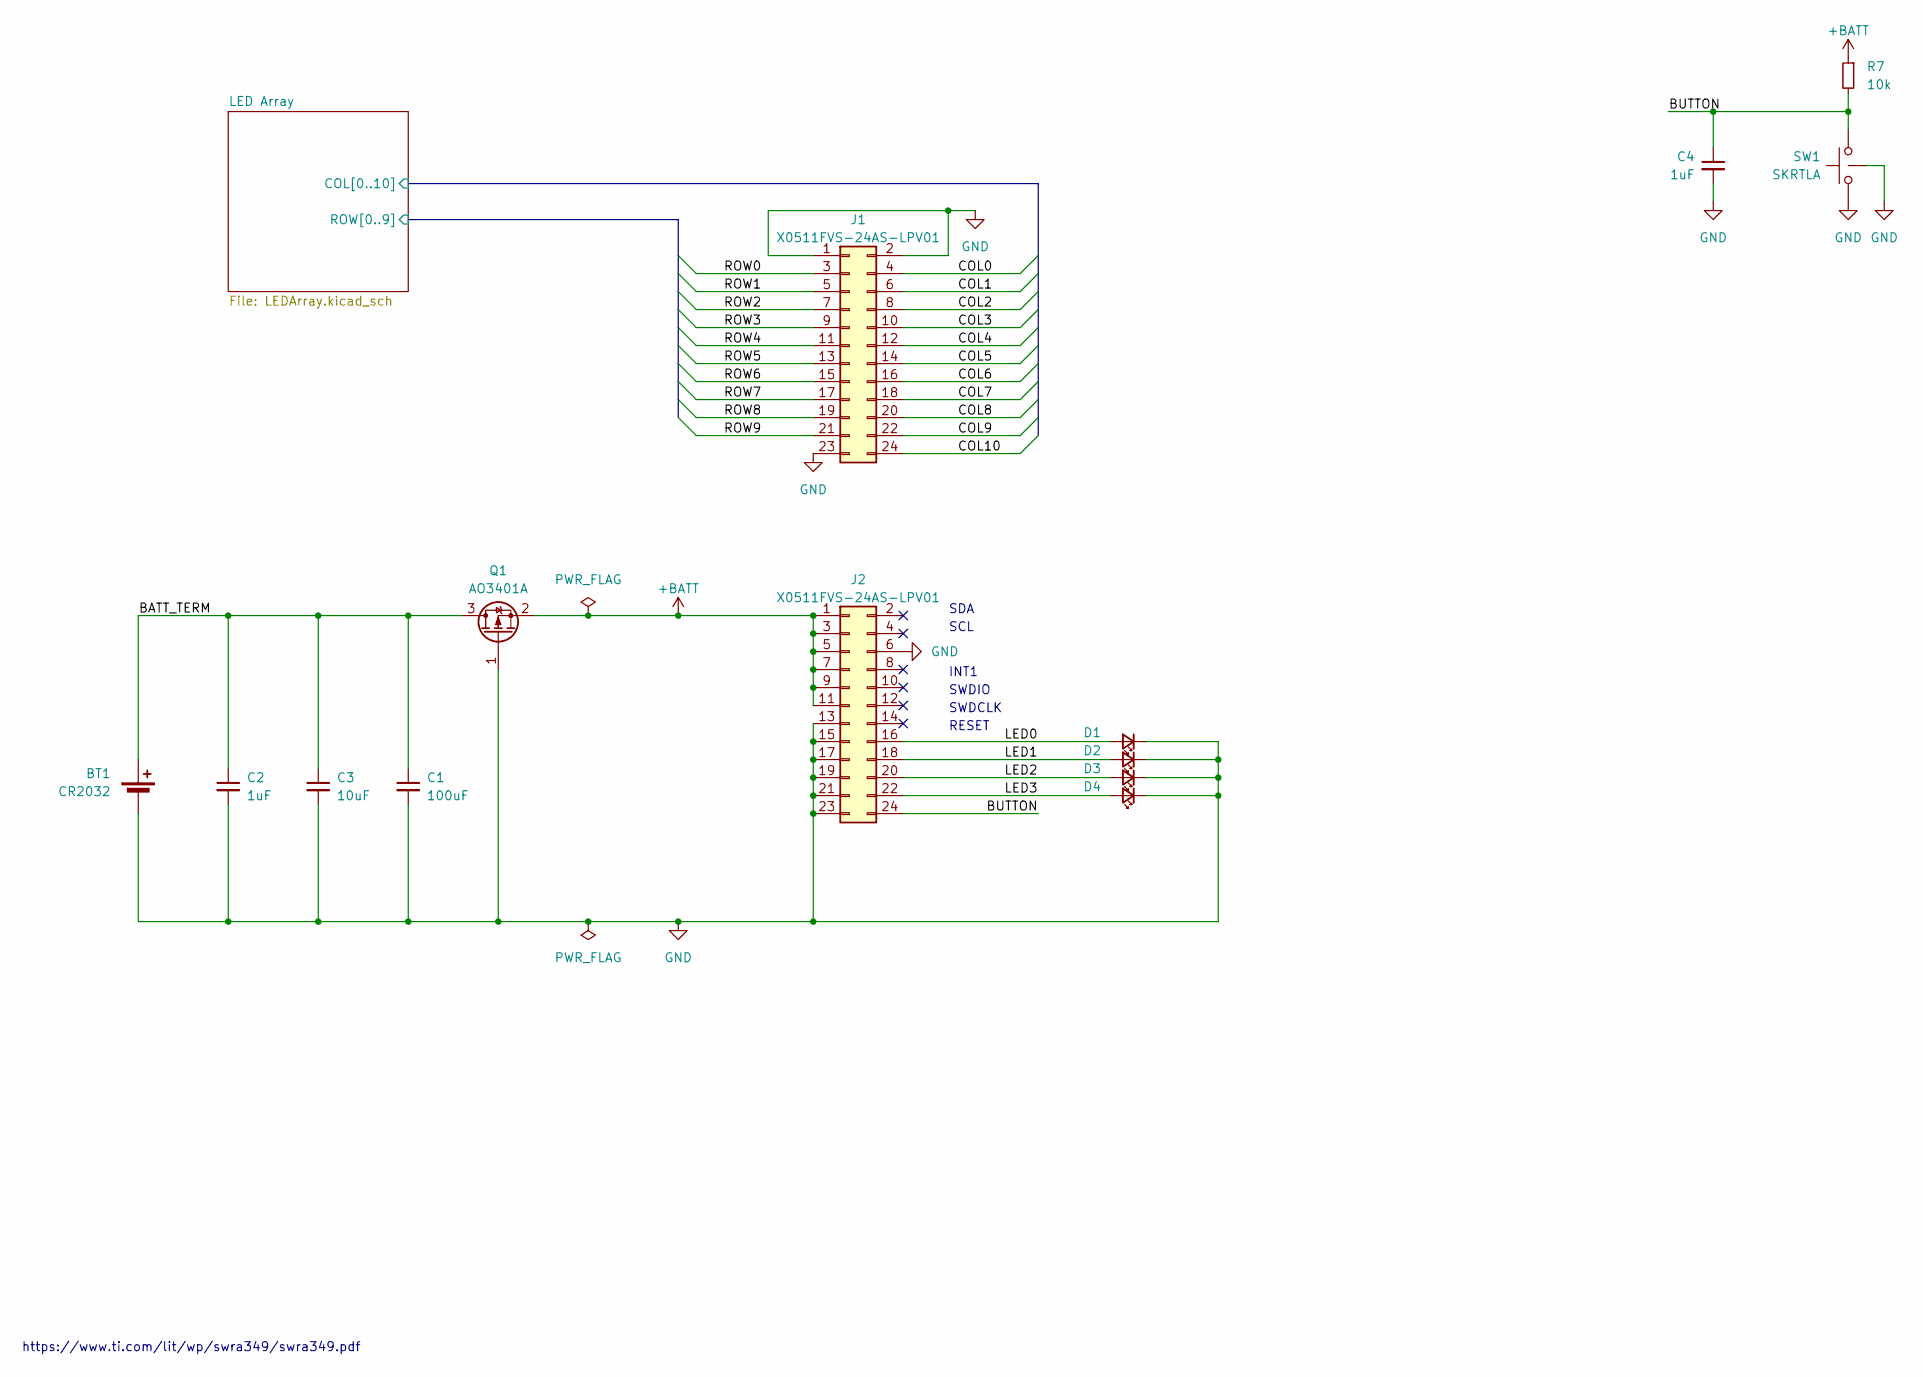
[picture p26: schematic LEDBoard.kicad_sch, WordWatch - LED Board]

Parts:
BT1: CR2032; BatteryHolder_Keystone_1060_1x2032
C1: 100uF; C_1206_3216Metric
C2, C4: 1uF; C_0402_1005Metric
C3: 10uF; C_0603_1608Metric
D1, D2, D3, D4: LED_Small; LED_0402_1005Metric
J1, J2: X0511FVS-24AS-LPV01
Q1: AO3401A; SOT-23
R7: 10k; R_0402_1005Metric
SW1: SKRTLA; SW_Push_1P1T-MP_NO_Horizontal_Alps_SKRTLAE010

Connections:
+BATT: J2.1, J2.3, J2.5, J2.7, J2.9, J2.11, Q1.2 (S), R7.1; also elsewhere on the board
/BATT_TERM: BT1.1 (+), C1.1, C2.1, C3.1, Q1.3 (D)
/BUTTON: C4.1, J2.24, R7.2, SW1.2
/LED0: D1.2 (A), J2.16
/LED1: D2.2 (A), J2.18
/LED2: D3.2 (A), J2.20
/LED3: D4.2 (A), J2.22
/LED Array/COL0: J1.4; also elsewhere on the board
/LED Array/COL1: J1.6; also elsewhere on the board
/LED Array/COL2: J1.8; also elsewhere on the board
/LED Array/COL3: J1.10; also elsewhere on the board
/LED Array/COL4: J1.12; also elsewhere on the board
/LED Array/COL5: J1.14; also elsewhere on the board
/LED Array/COL6: J1.16; also elsewhere on the board
/LED Array/COL7: J1.18; also elsewhere on the board
/LED Array/COL8: J1.20; also elsewhere on the board
/LED Array/COL9: J1.22; also elsewhere on the board
/LED Array/COL10: J1.24; also elsewhere on the board
/LED Array/ROW0: J1.3; also elsewhere on the board
/LED Array/ROW1: J1.5; also elsewhere on the board
/LED Array/ROW2: J1.7; also elsewhere on the board
/LED Array/ROW3: J1.9; also elsewhere on the board
/LED Array/ROW4: J1.11; also elsewhere on the board
/LED Array/ROW5: J1.13; also elsewhere on the board
/LED Array/ROW6: J1.15; also elsewhere on the board
/LED Array/ROW7: J1.17; also elsewhere on the board
/LED Array/ROW8: J1.19; also elsewhere on the board
/LED Array/ROW9: J1.21; also elsewhere on the board
GND: BT1.2 (-), C1.2, C2.2, C3.2, C4.2, D1.1 (K), D2.1 (K), D3.1 (K), D4.1 (K), J1.1, J1.2, J1.23, J2.6, J2.13, J2.15, J2.17, J2.19, J2.21, J2.23, Q1.1 (G), SW1.1, SW1.MP; also elsewhere on the board

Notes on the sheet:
SDA
SCL
SWDCLK
INT1
SWDIO
https://www.ti.com/lit/wp/swra349/swra349.pdf
RESET

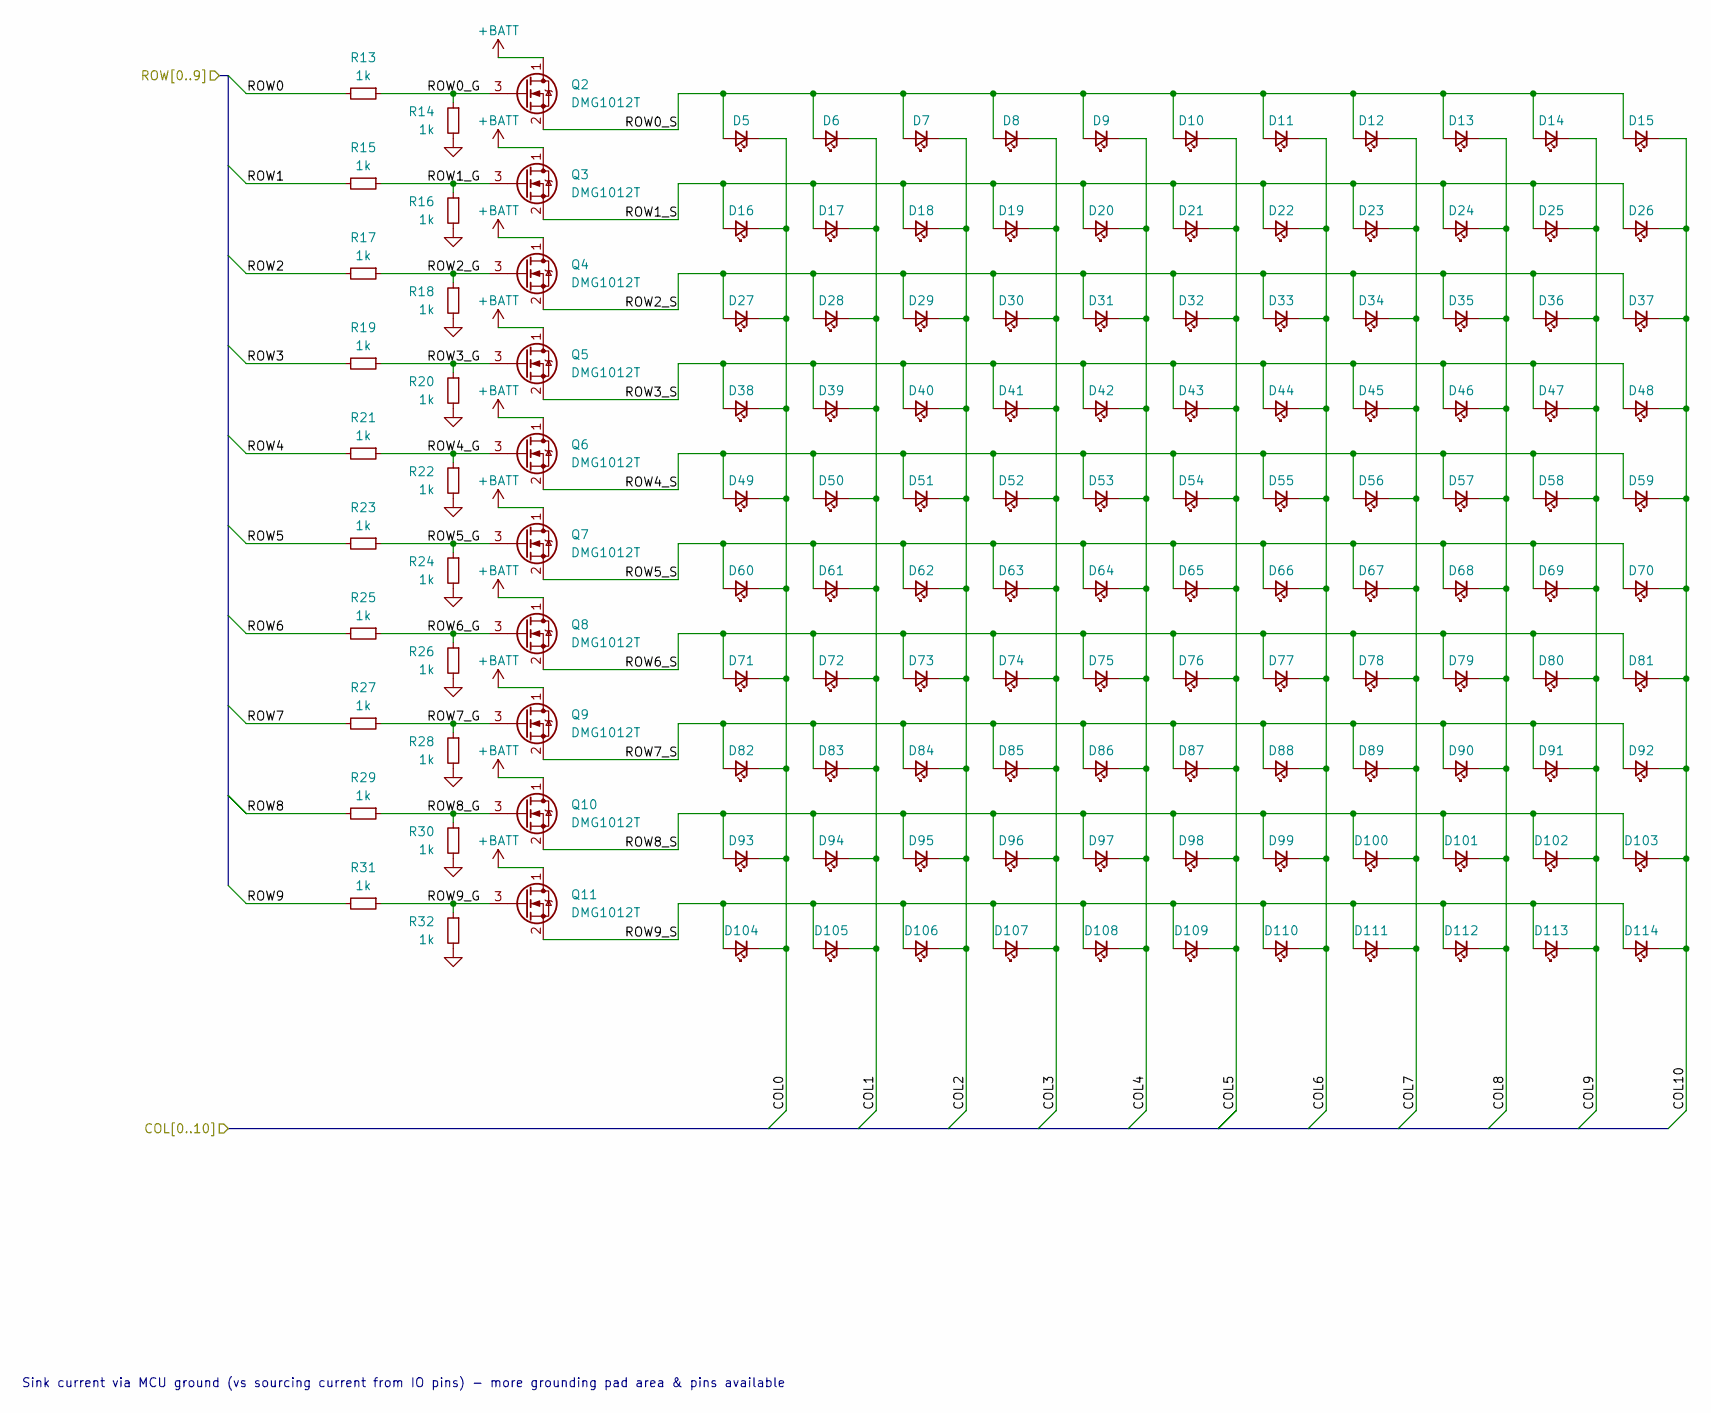
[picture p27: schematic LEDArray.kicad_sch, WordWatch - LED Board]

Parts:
D5, D6, D7, D8, D9, D10, D11, D12, D13, D14, D15, D16, D17, D18, D19, D20, D21, D22, D23, D24, D25, D26, D27, D28, D29, D30, D31, D32, D33, D34, D35, D36, D37, D38, D39, D40, D41, D42, D43, D44, D45, D46, D47, D48, D49, D50, D51, D52, D53, D54, D55, D56, D57, D58, D59, D60, D61, D62, D63, D64, D65, D66, D67, D68, D69, D70, D71, D72, D73, D74, D75, D76, D77, D78, D79, D80, D81, D82, D83, D84, D85, D86, D87, D88, D89, D90, D91, D92, D93, D94, D95, D96, D97, D98, D99, D100, D101, D102, D103, D104, D105, D106, D107, D108, D109, D110, D111, D112, D113, D114: LED_Small; LED_0402_1005Metric
Q2, Q3, Q4, Q5, Q6, Q7, Q8, Q9, Q10, Q11: DMG1012T; SOT-523
R13, R14, R15, R16, R17, R18, R19, R20, R21, R22, R23, R24, R25, R26, R27, R28, R29, R30, R31, R32: 1k; R_0402_1005Metric

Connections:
+BATT: Q2.1 (D), Q3.1 (D), Q4.1 (D), Q5.1 (D), Q6.1 (D), Q7.1 (D), Q8.1 (D), Q9.1 (D), Q10.1 (D), Q11.1 (D); also elsewhere on the board
/LED Array/COL0: D5.1 (K), D16.1 (K), D27.1 (K), D38.1 (K), D49.1 (K), D60.1 (K), D71.1 (K), D82.1 (K), D93.1 (K), D104.1 (K); also elsewhere on the board
/LED Array/COL1: D6.1 (K), D17.1 (K), D28.1 (K), D39.1 (K), D50.1 (K), D61.1 (K), D72.1 (K), D83.1 (K), D94.1 (K), D105.1 (K); also elsewhere on the board
/LED Array/COL2: D7.1 (K), D18.1 (K), D29.1 (K), D40.1 (K), D51.1 (K), D62.1 (K), D73.1 (K), D84.1 (K), D95.1 (K), D106.1 (K); also elsewhere on the board
/LED Array/COL3: D8.1 (K), D19.1 (K), D30.1 (K), D41.1 (K), D52.1 (K), D63.1 (K), D74.1 (K), D85.1 (K), D96.1 (K), D107.1 (K); also elsewhere on the board
/LED Array/COL4: D9.1 (K), D20.1 (K), D31.1 (K), D42.1 (K), D53.1 (K), D64.1 (K), D75.1 (K), D86.1 (K), D97.1 (K), D108.1 (K); also elsewhere on the board
/LED Array/COL5: D10.1 (K), D21.1 (K), D32.1 (K), D43.1 (K), D54.1 (K), D65.1 (K), D76.1 (K), D87.1 (K), D98.1 (K), D109.1 (K); also elsewhere on the board
/LED Array/COL6: D11.1 (K), D22.1 (K), D33.1 (K), D44.1 (K), D55.1 (K), D66.1 (K), D77.1 (K), D88.1 (K), D99.1 (K), D110.1 (K); also elsewhere on the board
/LED Array/COL7: D12.1 (K), D23.1 (K), D34.1 (K), D45.1 (K), D56.1 (K), D67.1 (K), D78.1 (K), D89.1 (K), D100.1 (K), D111.1 (K); also elsewhere on the board
/LED Array/COL8: D13.1 (K), D24.1 (K), D35.1 (K), D46.1 (K), D57.1 (K), D68.1 (K), D79.1 (K), D90.1 (K), D101.1 (K), D112.1 (K); also elsewhere on the board
/LED Array/COL9: D14.1 (K), D25.1 (K), D36.1 (K), D47.1 (K), D58.1 (K), D69.1 (K), D80.1 (K), D91.1 (K), D102.1 (K), D113.1 (K); also elsewhere on the board
/LED Array/COL10: D15.1 (K), D26.1 (K), D37.1 (K), D48.1 (K), D59.1 (K), D70.1 (K), D81.1 (K), D92.1 (K), D103.1 (K), D114.1 (K); also elsewhere on the board
/LED Array/ROW0: R13.2; also elsewhere on the board
/LED Array/ROW0_G: Q2.3 (G), R13.1, R14.1
/LED Array/ROW0_S: D5.2 (A), D6.2 (A), D7.2 (A), D8.2 (A), D9.2 (A), D10.2 (A), D11.2 (A), D12.2 (A), D13.2 (A), D14.2 (A), D15.2 (A), Q2.2 (S)
/LED Array/ROW1: R15.2; also elsewhere on the board
/LED Array/ROW1_G: Q3.3 (G), R15.1, R16.1
/LED Array/ROW1_S: D16.2 (A), D17.2 (A), D18.2 (A), D19.2 (A), D20.2 (A), D21.2 (A), D22.2 (A), D23.2 (A), D24.2 (A), D25.2 (A), D26.2 (A), Q3.2 (S)
/LED Array/ROW2: R17.2; also elsewhere on the board
/LED Array/ROW2_G: Q4.3 (G), R17.1, R18.1
/LED Array/ROW2_S: D27.2 (A), D28.2 (A), D29.2 (A), D30.2 (A), D31.2 (A), D32.2 (A), D33.2 (A), D34.2 (A), D35.2 (A), D36.2 (A), D37.2 (A), Q4.2 (S)
/LED Array/ROW3: R19.2; also elsewhere on the board
/LED Array/ROW3_G: Q5.3 (G), R19.1, R20.1
/LED Array/ROW3_S: D38.2 (A), D39.2 (A), D40.2 (A), D41.2 (A), D42.2 (A), D43.2 (A), D44.2 (A), D45.2 (A), D46.2 (A), D47.2 (A), D48.2 (A), Q5.2 (S)
/LED Array/ROW4: R21.2; also elsewhere on the board
/LED Array/ROW4_G: Q6.3 (G), R21.1, R22.1
/LED Array/ROW4_S: D49.2 (A), D50.2 (A), D51.2 (A), D52.2 (A), D53.2 (A), D54.2 (A), D55.2 (A), D56.2 (A), D57.2 (A), D58.2 (A), D59.2 (A), Q6.2 (S)
/LED Array/ROW5: R23.2; also elsewhere on the board
/LED Array/ROW5_G: Q7.3 (G), R23.1, R24.1
/LED Array/ROW5_S: D60.2 (A), D61.2 (A), D62.2 (A), D63.2 (A), D64.2 (A), D65.2 (A), D66.2 (A), D67.2 (A), D68.2 (A), D69.2 (A), D70.2 (A), Q7.2 (S)
/LED Array/ROW6: R25.2; also elsewhere on the board
/LED Array/ROW6_G: Q8.3 (G), R25.1, R26.1
/LED Array/ROW6_S: D71.2 (A), D72.2 (A), D73.2 (A), D74.2 (A), D75.2 (A), D76.2 (A), D77.2 (A), D78.2 (A), D79.2 (A), D80.2 (A), D81.2 (A), Q8.2 (S)
/LED Array/ROW7: R27.2; also elsewhere on the board
/LED Array/ROW7_G: Q9.3 (G), R27.1, R28.1
/LED Array/ROW7_S: D82.2 (A), D83.2 (A), D84.2 (A), D85.2 (A), D86.2 (A), D87.2 (A), D88.2 (A), D89.2 (A), D90.2 (A), D91.2 (A), D92.2 (A), Q9.2 (S)
/LED Array/ROW8: R29.2; also elsewhere on the board
/LED Array/ROW8_G: Q10.3 (G), R29.1, R30.1
/LED Array/ROW8_S: D93.2 (A), D94.2 (A), D95.2 (A), D96.2 (A), D97.2 (A), D98.2 (A), D99.2 (A), D100.2 (A), D101.2 (A), D102.2 (A), D103.2 (A), Q10.2 (S)
/LED Array/ROW9: R31.2; also elsewhere on the board
/LED Array/ROW9_G: Q11.3 (G), R31.1, R32.1
/LED Array/ROW9_S: D104.2 (A), D105.2 (A), D106.2 (A), D107.2 (A), D108.2 (A), D109.2 (A), D110.2 (A), D111.2 (A), D112.2 (A), D113.2 (A), D114.2 (A), Q11.2 (S)
GND: R14.2, R16.2, R18.2, R20.2, R22.2, R24.2, R26.2, R28.2, R30.2, R32.2; also elsewhere on the board

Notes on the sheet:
Sink current via MCU ground (vs sourcing current from IO pins) - more grounding pad area & pins available

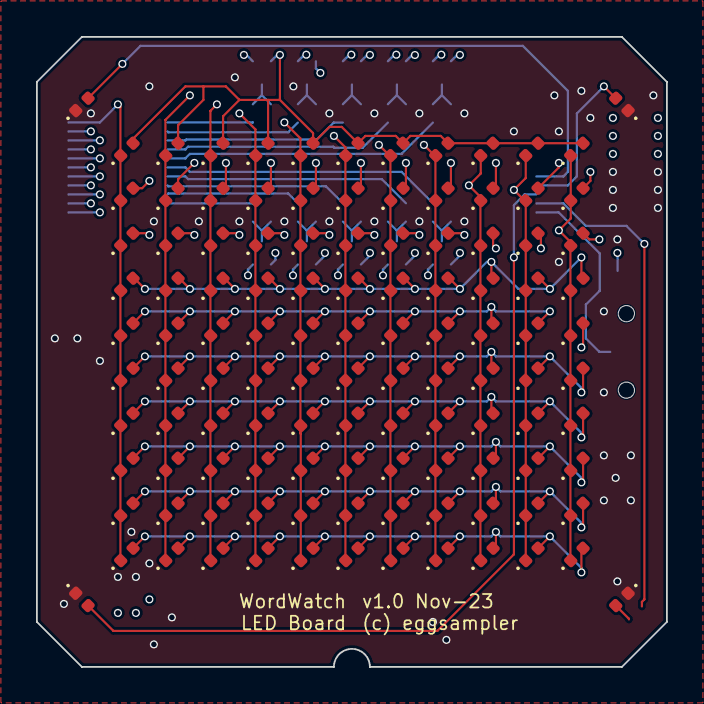
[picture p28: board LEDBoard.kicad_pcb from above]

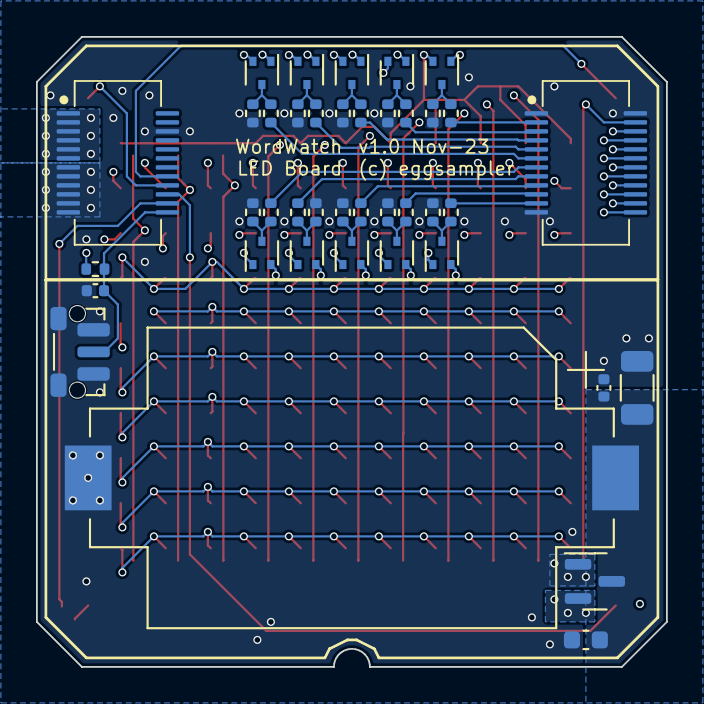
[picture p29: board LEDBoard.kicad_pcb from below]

Board: 4 copper layers, 35.0 x 35.0 mm, 154 parts (40 on the bottom side), 49 nets.

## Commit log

2023-10-31 Commit design files
    [Accelerometer.kicad_sch, BOM-ControllerBoard.csv, BOM-LEDBoard.csv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]
2023-11-05 Minor board updates
    [BOM-LEDBoard.csv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]
2023-11-08 Remove LED driver
    [Accelerometer.kicad_sch, BOM-ControllerBoard.csv, BOM-LEDBoard.csv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]
2023-11-08 Small fixes for plotting
    [ControllerBoard.kicad_pcb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]
2023-11-08 Remove all via in pad on controller board where possible
    [CPL-ControllerBoard.csv, ControllerBoard-CuBottom.gbr, ControllerBoard-CuIn1.gbr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]
2023-11-09 Remove all via in pad on led board where possible
    [CPL-LEDBoard.csv, LEDBoard-CuBottom.gbr, LEDBoard-CuIn1.gbr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]
2023-11-11 Change led matrix routing for sinking current through mcu, sourcing from battery
    [Accelerometer.kicad_sch, BOM-ControllerBoard.csv, BOM-LEDBoard.csv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]
2023-11-11 Fix programming board plot, add extra library files
    [ProgrammingBoard-CuBottom.gbr, ProgrammingBoard-CuIn1.gbr, ProgrammingBoard-CuIn2.gbr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]
2023-11-11 Update control board silkscreen
    [ControllerBoard-CuBottom.gbr, ControllerBoard-CuIn1.gbr, ControllerBoard-CuIn2.gbr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]
